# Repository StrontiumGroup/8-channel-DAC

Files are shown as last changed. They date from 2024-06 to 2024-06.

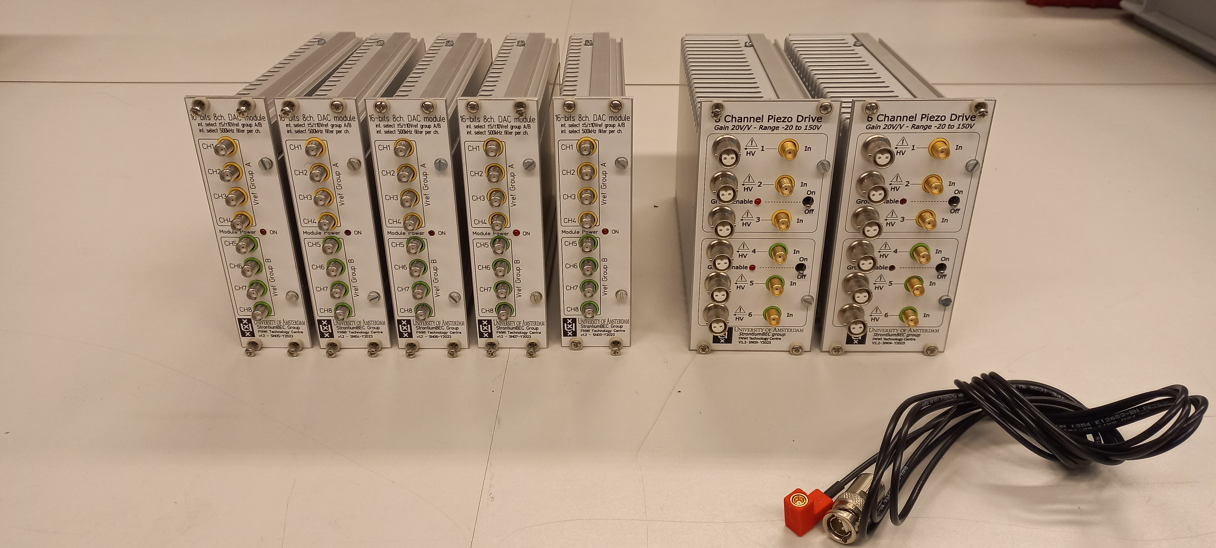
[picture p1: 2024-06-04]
Pictures/SN03-7.jpg

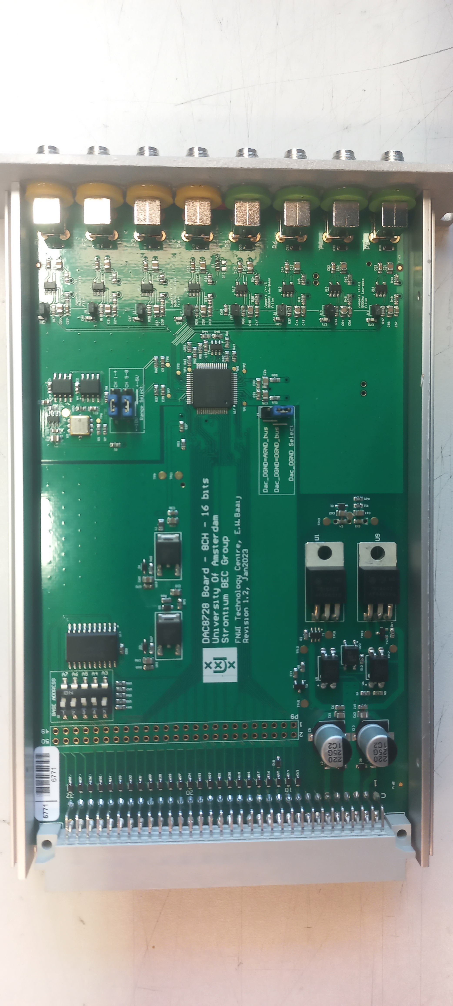
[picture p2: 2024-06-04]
Pictures/SN02/20230306_154427.jpg

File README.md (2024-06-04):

DAC_Module_V12_2
DAC_Module_V12_1
SN03-7 modified
Untitled picture2
![Uploading Untitled picture.png…]()

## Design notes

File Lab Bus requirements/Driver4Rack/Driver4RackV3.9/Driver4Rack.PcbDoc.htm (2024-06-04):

Reporting Options

# File in Previous Format

Date | : | 24/06/2022
Time | : | 11:39:30
Filename | : | U:\iqclock\Electronics\Designs\Driver4Rack\Driver4RackV3.9\Driver4Rack.PcbDoc

Version | Warning
Release 12 | CAUTION - Air Gap Width previously controlled by Clearance rule is now controlled by Polygon Connect Style rule's newly introduced Air Gap Width (set to default value). Suggest reviewing each Polygon Connect Style rule's Air Gap Width attribute for correctness.
Release 13 | CAUTION - Silkscreen Over Component Pads Rules are converted to Silk To Solder Mask Clearance Rules. Suggest examining rule scopes for accuracy.

This file was generated by an earlier version of the software

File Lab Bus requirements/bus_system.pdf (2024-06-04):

A Simple Parallel Bus

Computer Control System
for Atomic Physics Experiments

### Todd P. Meyrath¹ Florian Schreck

Atom Optics Laboratory
Center for Nonlinear Dynamics University of Texas at Austin

c 2004 by the authors
March 6, 2004
revised March 25, 2004

Here we present a simple computer control system concept based on a parallel 16-bit bidirectional data bus, parallel 8-bit address bus, and strobe signal. This represents a particularly simple to understand and flexible system that is suited for a wide range of experimental control. In particular, we use it for cold atom experiments. Nothing here is specific to atom physics, many experimental systems could benefit from such a control system. Although these concepts are well known in the hardware community and everything here represents old technology, much has been unknown to the experimental atom physics community. Our implementation may be considered a brute-force method were most devices used can largely be considered unintegrated whereas they are very flexible and appropriate for use as laboratory electronics. The simplicity of the parallel bus allows easy interfacing with many devices including Digital-to-Analog Converter (DAC), Analog-to-Digital Converter (ADC), Direct Digital Synthesis (DDS), microprocessors, etc. Another important aspect of this method is simplicity of construction in that the hardware is available from many electronics distributors and can be fabricated in a few weeks by undergraduates or graduate students.
Figure 1 gives an overview of the system we are using. This setup involves a National Instruments board, however, see below for other implementation ideas. The elements of Figure 1 are as follows:
- Part A: The National instruments card requires a special cable using a peculiar hardware connector. The order of the signal lines are awkward on this cable. Adapter board A sorts the signals out and distributes them to four 8 bit flat ribbon connectors.
- Part B: Cable B has to be constructed combining those four 8 bit flat ribbon cables in one 25 bit and one 7 bit flat ribbon cable. The bit order of this cable

1Please send comments, questions, corrections, insults to meyrath@physics.utexas.edu

1

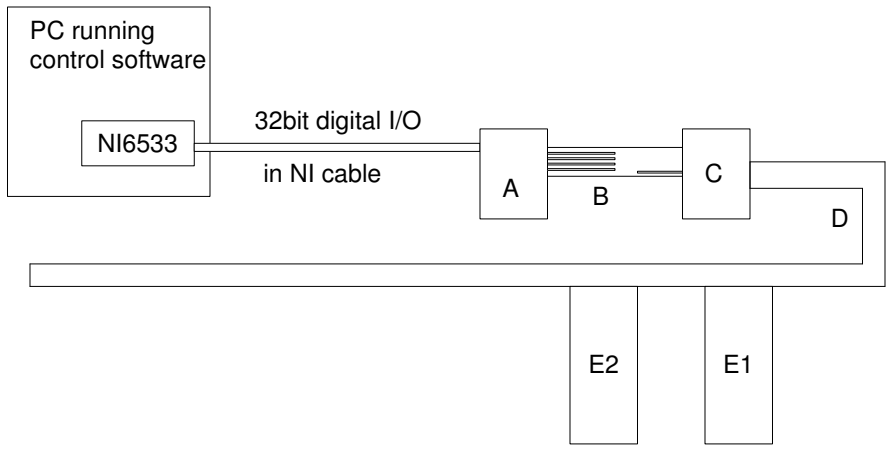
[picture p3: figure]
PC running control software; 32bit digital I/O; in NI cable

A: NI cable to flat ribbon cable converter board

NI = National Instruments

B: 4x 8 bit to
1x25 bit + 1x7 bit
converter flat ribbon cable

C: bus transceivers and
strobe pulse generator board D: 25 bit flat ribbon bus cable

Ex: digital or analog output PCB

Remark: the NI6533 cards and parts A,B can be exchanged eg. with the USB port and a USB to parallel converter

Figure 1: General layout of the control system.

is the obvious one, port A,B,C, and bit 0 of port D go to the 50 pin header (see below) and bits 1 to 7 of port D go to the 7pin header. Signal and ground lines alternate in the flat ribbon cables. The headers must be crimped in the correct orientation on the cable so that bit zero of port A goes to bit 0 of the 25 bit bus and so forth. We used a 50 line flat ribbon cable and an additional 14 line cable next to it.

- Part C is the strobe bit generator and transceiver board. It buffers the NI6533 card signals in addition to producing a time shortened strobe bit signal. The schematic and layout are at the end of this document.
- Part D is the bus system 50 line flat ribbon cable. The pin configuration com-patible with our output devices is given below. It is suggested that an additional buffer board be used if the ribbon cable it to travel a long distance.
- Part E1: 16-bit devices.

Concept: The concept of the system is illustrated in Figure 3. The system consists of a 16-bit data bus, an 8-bit address bus, and a clock. The clock is converted into a strobe signal. The strobe commands the device to update its data, see next

2

section. All 25 bits are sent to all devices but only one accepts the data. Each device has a local 8-bit address which is set on the Printed Circuit Board (PCB) of that device with DIP switches. Only when the input 8-bit address bus matches does the device accept the strobe signal. With this system, one may add up to 2⁸ devices onto the bus, one of which is accessed each clock cycle.
The data bus, in fact, may be bidirectional which allows for input data as well. Our buffer/strobe generator board (see below) includes transceiver buffers which can operate bidirectionally. This requires an additional bit in the bus which talks to this board and chooses the data bus direction. In this case, it is the responsibility of the computer to address the appropriate input device. As of this writing, we have not implemented the use of this input option, but it is in principle a simple addition.

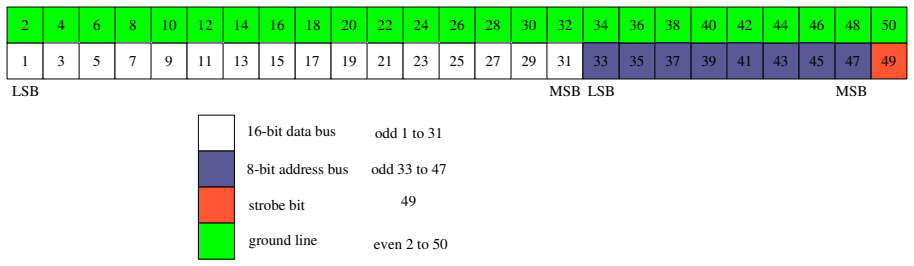
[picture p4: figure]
16-bit data bus; 8-bit address bus; strobe bit; ground line; LSB; MSB; odd 1 to 31; odd 33 to 47; even 2 to 50

Figure 2: Pin configuration for 50-pin connector.

Why a Strobe? The strobe serves two purposes: increase data rate and signal error protection. Firstly, the data loading implementation in a similar system is typically accomplished in three clock cycles: data input, strobe on, strobe off. This can be improved by using a time shortened pulse for the strobe rather than full clock cycles. The strobe pulse occurs in the center of each clock period and has no dependance on clock state, only state change. Our strobe pulses are typically order 100 ns in length in the middle of the order 2 µs (500 kHz clock) clock periods. This concept, along with out circuit implementation schematic is shown in Figure 4. The figure inset shows a pictorial diagram of the strobe timing.
Computer Output: How the computer actually generates the needed bus bits is flexible. The method we currently use involves a N16533 from National Instruments. This device gives an synchronous 32-bit parallel bus and clock signal which we have typically run between 500 kHz and 750 kHz. Such a fancy device is not to-tally needed (we used it because we had it). The computer outputs can be produced synchronously using other methods, a few of which we will suggest here in words. One method that could be used is the computer’s built-in parallel printer port. This port has an 8-bit parallel I/O and various handshaking bits. In this case, the clock would be put external to the computer along with an 8-bit output FIFO, 24 or 32-bits worth of latches (74LS573) and a few logic chips. The basic idea is to put the asyn-chronous computer output of the parallel port into the FIFO which is synchronously triggered by the local clock and multiplexed to 24 or 32 bits and latched. The FIFO is First In First Out and consists of a triggered buffer, there are bunches of single

3

chip FIFOs available. A similar option is to use a USB device such as DLP-USB245M (available from mouser electronics for $25). This device accepts a USB (Universal Serial Bus) connection from the computer and has a built-in synchronous FIFO 8-bit parallel output and would require only a few logic chips and latches to implement. Evidently the manufacturer of this USB-FIFO device provides all the simple codes for programming the device, although we have not used it. The only real disadvantage of these two suggestions to the National Instruments card is the bus speed which may be limited to a few hundred kHz. The two major advantages of these systems are: they are really cheap (order $50) compared to NI cards (order $1500), and secondly, with the printer port or USB port implementation, it is portable to any computer. Another interesting option could be to use a Firewire port and implement it similar to the USB as discussed here if some convenient protocol devices exist. Firewire has the advantage of running at 300Mbps (tak bystro!).
Example Devices: Our goal here is flexible laboratory electronics. A com-mon laboratory implementation uses BNC type outputs which connect devices under computer control to the real-world experimental (analog) devices. Typically, desired computer output comes in the form of lone digital trigger signals and analog signals. We, therefore, have built two device types for this bus system. The first is a simple buffered set of digital outputs. In this case a single ‘16-bit device’ as discussed in Figure 3 consists of 16 latched digital outputs equipped with line drivers. The second device type is analog. In this design, we use some very nice modern 16-bit DAC ICs. Here, a single analog line is a 16-bit device. Our design for this includes 8 analog outputs on a single PCB, each of which has a full -10 to +10 V range and 16 bit accuracy as well as 1/4 A line driving capacity. Schematics, layouts and detailed descriptions for both of these device types are available at the web site: george.ph.utexas.edu/~control
Because of the generality of this system, one could easily make other output devices such as DDS type radio frequency generators, etc. Additionally, as discussed before, ADC’s could be added using the input mode of the data bus.

4

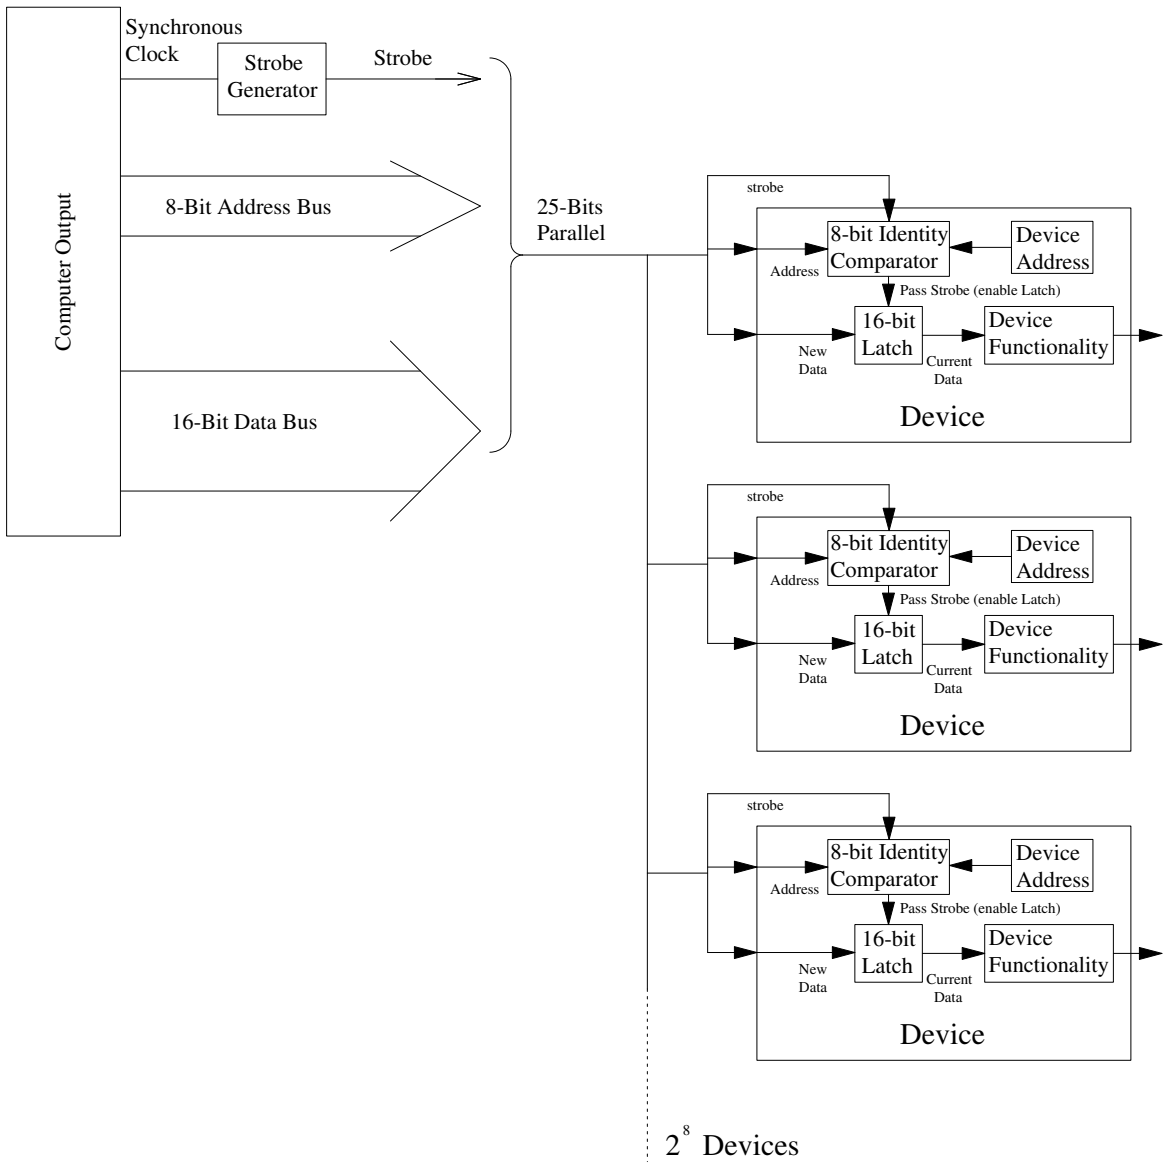
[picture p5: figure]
Synchronous; Clock; Strobe; Generator; 8-Bit Address Bus; 16-Bit Data Bus; Computer Output; 25-Bits Parallel; Device; Device Address; 8-bit Identity Comparator; Device Functionality; Current Data; 16-bit; New; Latch; Data; Address; Pass Strobe (enable Latch); strobe; 2 Devices ⁸

Figure 3: Output Concept. Each 16-bit device has its own 8-bit address which typically may be set locally with DIP switches. All devices receive all 25 bits on each clock cycle, but only the device with matching address accepts the strobe bit which commands it to take the new data.

5

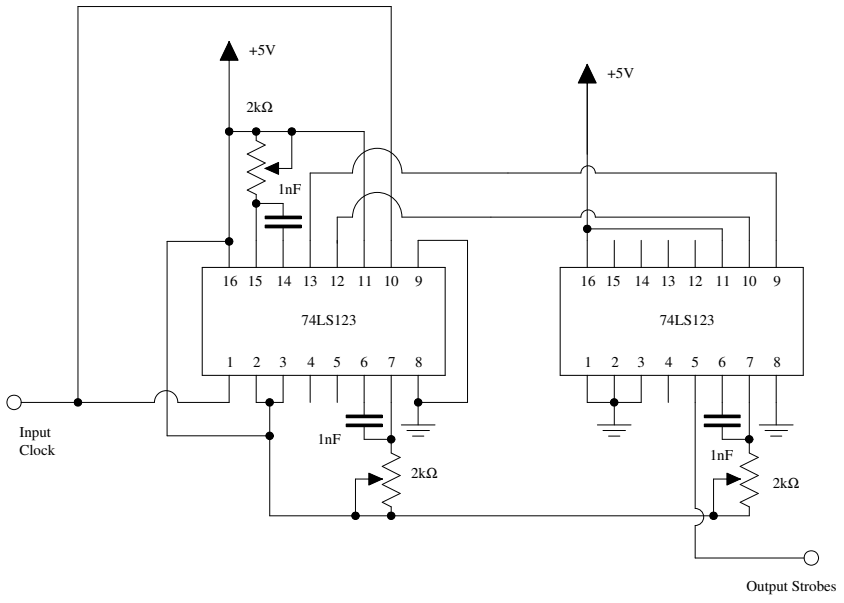
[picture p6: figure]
Input Clock; Output Strobes
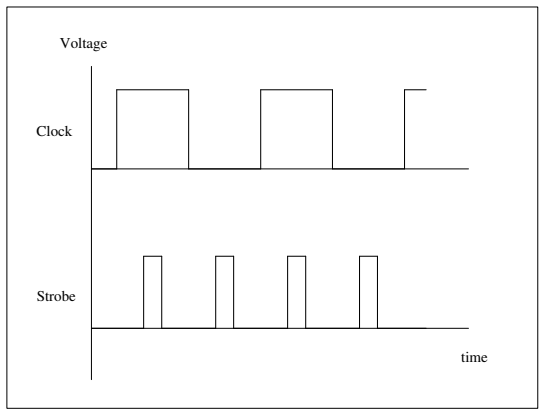
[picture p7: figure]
time; Voltage; Clock; Strobe

Triple Data Rate Strobe

Figure 4: Strobe Generator. Note, that the strobe bit can be high or low active (switching output pins 12 to 5). In this design, we have chosen it to be high because that is the logic used on our digital output board designs. Please note in the case of the analog output board, that the active strobe may be chosen to be high or low. Which is to say, for using this strobe generator design, the analog output boards must always have the DIP switch set to properly accept a high strobe. See documentation on the digital and analog output board designs.

6

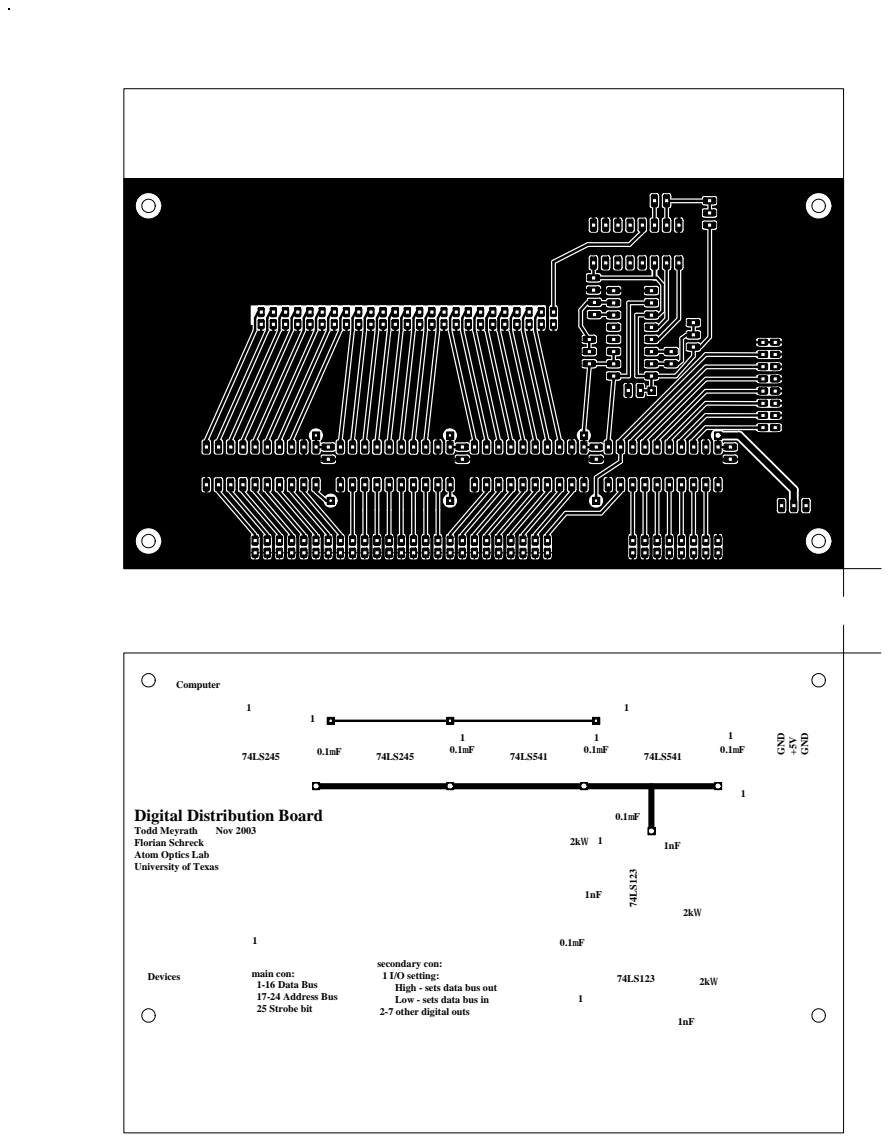
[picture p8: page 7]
Computer; Devices; main con:; 1-16 Data Bus 17-24 Address Bus 25 Strobe bit; GND; Todd Meyrath; Nov 2003

Digital Distribution Board
Florian Schreck
Atom Optics Lab
University of Texas

secondary con:
1 I/O setting:
High - sets data bus out
Low - sets data bus in
2-7 other digital outs

Bus buffer, strobe generator and NI6533 adapter board

Gerhard Hendl, Florian Schreck and Todd Meyrath

This board provides several functions: it is an adapter between the NI6533 cable and the 50 pin header of the bus system, it can generate a strobe signal and it can have input lines for the NI6533 external clock and trigger. It can also be used just as a signal refreshing board within the 50 pin bus cable. It is possible to add zener diodes between the bus signal lines and ground to improve the signal quality. The remaining normally unused 7 bits of the NI6533 are available on a independent connecter. Those bits can for example be used in conjunction with an address decoder chip to put the strobe signal to the bus only if a certain bit pattern appears on these higher seven bits. In that way it is possible to use more than 256 different addresses. Or these bits can be used as additional digital outputs.
This board was designed by Gerhard Hendl of the institute for quantumoptics and quantuminformation of the Austrian academy of sciences at Innsbruck (gerhard.hendl at oeaw.ac.at).

1

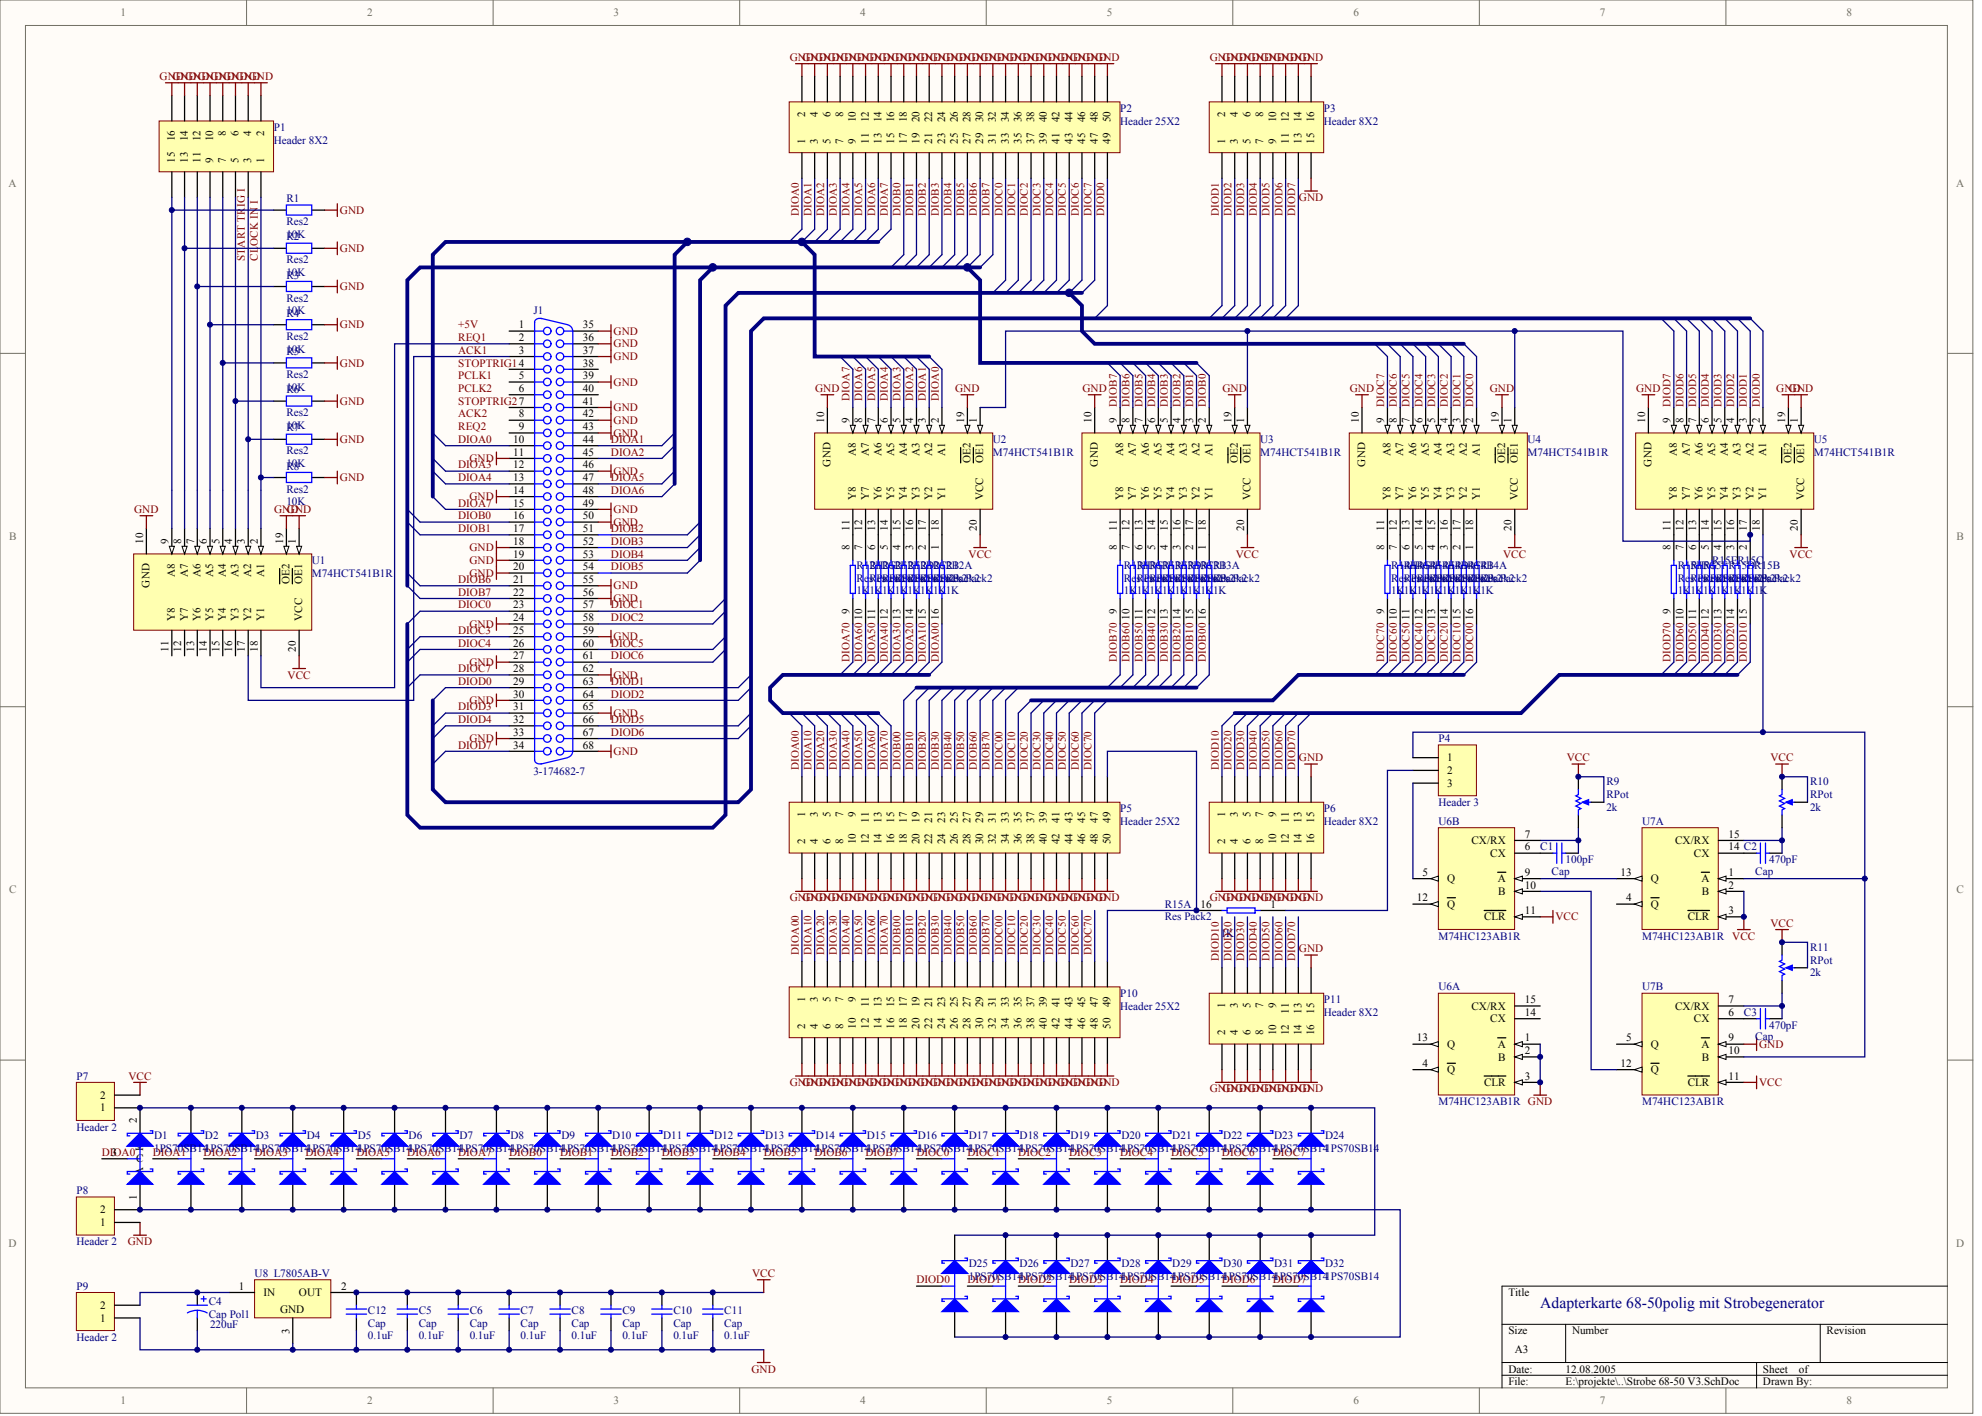
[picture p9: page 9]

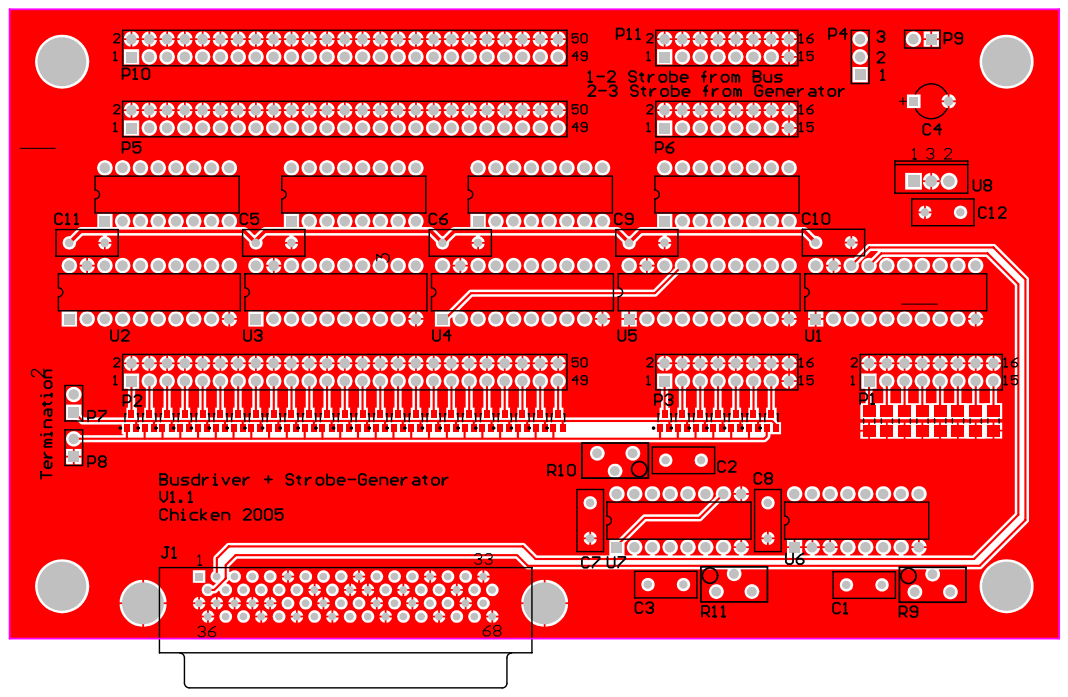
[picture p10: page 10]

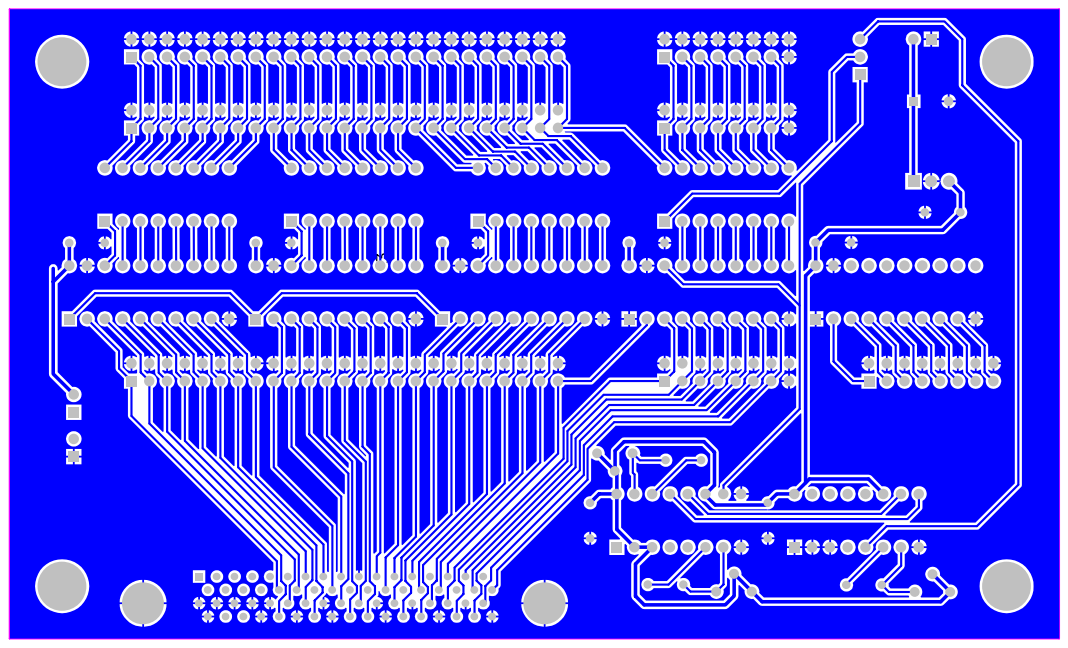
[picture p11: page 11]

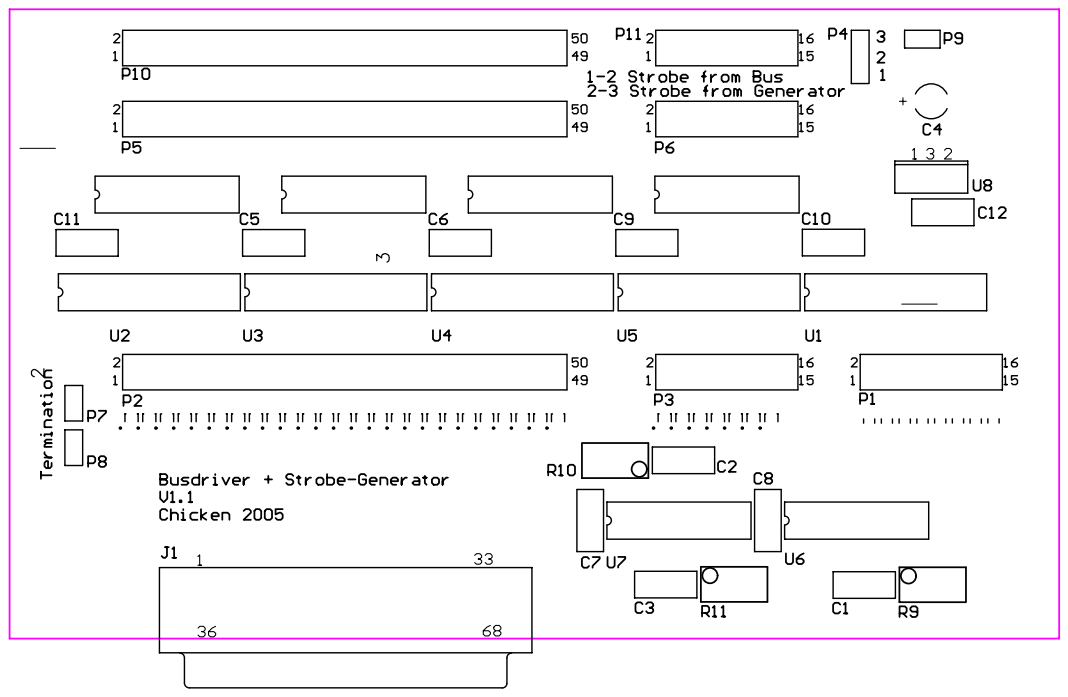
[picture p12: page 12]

Designator Description | Value LibRef | Footprint
C1 | Capacitor | 100pF Cap | RAD-0.2
C2 | Capacitor | 470pF Cap | RAD-0.2
C3 | Capacitor | 470pF Cap | RAD-0.2
C4 | Polarized Capacitor (Radial) | 220uF Cap Pol1 | CAPPR5-5x5
C5 | Capacitor | 0.1uF Cap | RAD-0.2
C6 | Capacitor | 0.1uF Cap | RAD-0.2
C7 | Capacitor | 0.1uF Cap | RAD-0.2
C8 | Capacitor | 0.1uF Cap | RAD-0.2
C9 | Capacitor | 0.1uF Cap | RAD-0.2
C10 | Capacitor | 0.1uF Cap | RAD-0.2
C11 | Capacitor | 0.1uF Cap | RAD-0.2
C12 | Capacitor | 0.1uF Cap | RAD-0.2
D1 | Schottky Barrier Double Diode | 1PS70SB14 | SOT323
D2 | Schottky Barrier Double Diode | 1PS70SB14 | SOT323
D3 | Schottky Barrier Double Diode | 1PS70SB14 | SOT323
D4 | Schottky Barrier Double Diode | 1PS70SB14 | SOT323
D5 | Schottky Barrier Double Diode | 1PS70SB14 | SOT323
D6 | Schottky Barrier Double Diode | 1PS70SB14 | SOT323
D7 | Schottky Barrier Double Diode | 1PS70SB14 | SOT323
D8 | Schottky Barrier Double Diode | 1PS70SB14 | SOT323
D9 | Schottky Barrier Double Diode | 1PS70SB14 | SOT323
D10 | Schottky Barrier Double Diode | 1PS70SB14 | SOT323
D11 | Schottky Barrier Double Diode | 1PS70SB14 | SOT323
D12 | Schottky Barrier Double Diode | 1PS70SB14 | SOT323
D13 | Schottky Barrier Double Diode | 1PS70SB14 | SOT323
D14 | Schottky Barrier Double Diode | 1PS70SB14 | SOT323
D15 | Schottky Barrier Double Diode | 1PS70SB14 | SOT323
D16 | Schottky Barrier Double Diode | 1PS70SB14 | SOT323
D17 | Schottky Barrier Double Diode | 1PS70SB14 | SOT323
D18 | Schottky Barrier Double Diode | 1PS70SB14 | SOT323
D19 | Schottky Barrier Double Diode | 1PS70SB14 | SOT323
D20 | Schottky Barrier Double Diode | 1PS70SB14 | SOT323
D21 | Schottky Barrier Double Diode | 1PS70SB14 | SOT323
D22 | Schottky Barrier Double Diode | 1PS70SB14 | SOT323
D23 | Schottky Barrier Double Diode | 1PS70SB14 | SOT323
D24 | Schottky Barrier Double Diode | 1PS70SB14 | SOT323
D25 | Schottky Barrier Double Diode | 1PS70SB14 | SOT323
D26 | Schottky Barrier Double Diode | 1PS70SB14 | SOT323
D27 | Schottky Barrier Double Diode | 1PS70SB14 | SOT323
D28 | Schottky Barrier Double Diode | 1PS70SB14 | SOT323
D29 | Schottky Barrier Double Diode | 1PS70SB14 | SOT323
D30 | Schottky Barrier Double Diode | 1PS70SB14 | SOT323
D31 | Schottky Barrier Double Diode | 1PS70SB14 | SOT323
D32 | Schottky Barrier Double Diode | 1PS70SB14 | SOT323
J1 | Plug Assembly, Horizontal with Kink | 3-174682-7 | 3-174682-7
P1 | Header, 8-Pin, Dual row | Header 8X2 | HDR2X8
P2 | Header, 25-Pin, Dual row | Header 25X2 | HDR2X25
P3 | Header, 8-Pin, Dual row | Header 8X2 | HDR2X8
P4 | Header, 3-Pin | Header 3 | HDR1X3
P5 | Header, 25-Pin, Dual row | Header 25X2 | HDR2X25
P6 | Header, 8-Pin, Dual row | Header 8X2 | HDR2X8
P7 | Header, 2-Pin | Header 2 | HDR1X2
P8 | Header, 2-Pin | Header 2 | HDR1X2
P9 | Header, 2-Pin | Header 2 | HDR1X2

P10 | Header, 25-Pin, Dual row | | Header 25X2 | HDR2X25
P11 | Header, 8-Pin, Dual row | | Header 8X2 | HDR2X8
R1 | Resistor | 10K | Res2 | cr3216-1206
R2 | Resistor | 10K | Res2 | cr3216-1206
R3 | Resistor | 10K | Res2 | cr3216-1206
R4 | Resistor | 10K | Res2 | cr3216-1206
R5 | Resistor | 10K | Res2 | cr3216-1206
R6 | Resistor | 10K | Res2 | cr3216-1206
R7 | Resistor | 10K | Res2 | cr3216-1206
R8 | Resistor | 10K | Res2 | cr3216-1206
R9 | Potentiometer | 2k | RPot | rpot3
R10 | Potentiometer | 2k | RPot | rpot3
R11 | Potentiometer | 2k | RPot | rpot3
R12 | Isolated Resistor Network - Parts | 1K | Res Pack2 | DIP-16
R13 | Isolated Resistor Network - Parts | 1K | Res Pack2 | DIP-16
R14 | Isolated Resistor Network - Parts | 1K | Res Pack2 | DIP-16
R15 | Isolated Resistor Network - Parts | 1K | Res Pack2 | DIP-16
U1 | Octal Bus Buffer with 3 State Outputs | M74HCT541B1R DIP20
U2 | Octal Bus Buffer with 3 State Outputs | M74HCT541B1R DIP20
U3 | Octal Bus Buffer with 3 State Outputs | M74HCT541B1R DIP20
U4 | Octal Bus Buffer with 3 State Outputs | M74HCT541B1R DIP20
U5 | Octal Bus Buffer with 3 State Outputs | M74HCT541B1R DIP20
U6 | Dual Retriggerable Monostable Multivibrator | M74HC123AB1R DIP16
U7 | Dual Retriggerable Monostable Multivibrator | M74HC123AB1R DIP16
U8 | Precision 1A Regulator | | L7805AB-V | TO220ABN

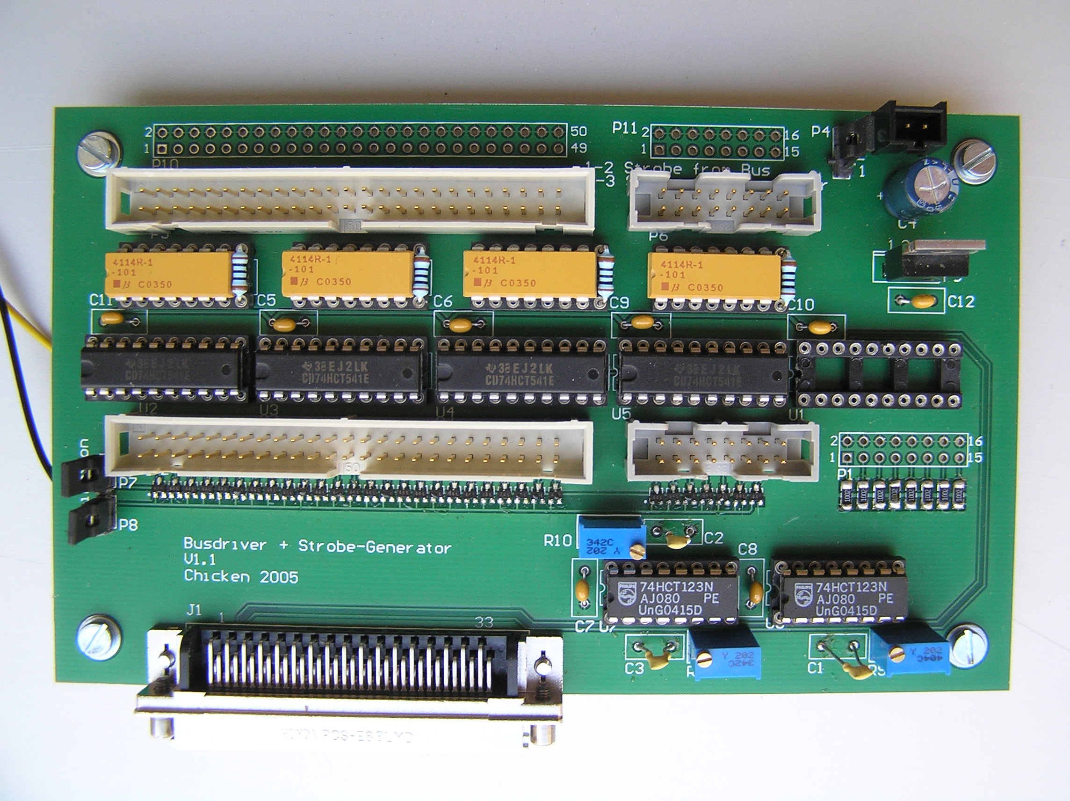
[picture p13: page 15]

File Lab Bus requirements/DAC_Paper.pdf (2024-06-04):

Octal 16-Bit DAC

### Todd P. Meyrath¹ Florian Schreck

Atom Optics Laboratory
Center for Nonlinear Dynamics University of Texas at Austin

c 2004 by the authors
December 14, 2003
revised March 24, 2005

See disclaimer²

Here, we present the design of an octal 16-bit DAC based on the DAC7744 from Texas Instruments. The device here is general purpose and may be easily controlled by a variety of systems involving a simple parallel bus. The basic features are as follows:

Eight channels per board:

- 8-Bit parallel input address bus (plus one strobe bit, 9 total)
- 3 lowest bits select DAC on board (see output table below), the other 5 bits are board select with local address set by DIP switches. The strobe bit also has a DIP switch so it may be set as a high or a low strobe as desired.
- typical digital clock frequency may be 100 kHz to 1 MHz (we use 500 kHz) for 24 input bits (plus one time narrowed strobe bit), 12 to 24 Mbps.

Each Channel:

- 16-Bit accuracy
- ±10V scale, reference drift 3ppm/C, easy to change to ±5V by using different values of the LT1019 reference series.
- Buffered BNC outputs for 50 Ω loads, 250 mA max per channel

Advantages and Disadvantages:
The circuit is relatively simple to understand from the schematic and is competi-tive with professional output boards such as those produced by National Instruments.

1Please send comments, questions, corrections, insults to meyrath@physics.utexas.edu 2Disclaimer: The author provides this and other designs on the web as a courtesy. There is no guarantee on this or any other designs presented, use at your own risk. The author also comments that the suggested parts used are not an endorsement of any manufacturer or distributer.

1

A principle disadvantage of this design is cross talk. As opposed to a design with

### 8 totally independent DACs and voltage references, this design uses the DAC7744

quad DAC sharing voltage references among the four outputs. This may produce cross talk of order the least significant bit between the four channels when sweep-ing. The circuit has several advantages: firstly, it is inexpensive in comparison to National Instruments boards (order $1500). This circuit costs about $200 ($50 per PCB when buying 10, $45 per DAC IC (2), plus output buffers, opamps, capacitors, logic circuits) and the fun of building it yourself! A second advantage is the control bus, this setup allows one to set up a data and address bus system however one wants (digital output board, parallel port, USB to parallel, etc). The addressing and data writing is very simple with a 16-bit parallel data bus and an 8-bit parallel address bus. This means that the computer may control many such boards or other types using a similar bus setup. The digital lines may also extend far from the computer along a single 50 conductor ribbon cable. This may allow one to keep the precision analog outputs short. Our system using 8 address bits may have as many as 256 16-bit analog outputs (unless addresses are used for other devices as well). Naturally only one 16-bit output may be addressed on a single digital cycle, however, for the cold atom experiments that we run this is hardly a limitation. We run our digital bus at 500 kHz. The circuit is in convenient form for laboratory electronics with BNC outputs which are buffered to drive the common 50 Ω loads. The board may be easily panel mounted in an enclosure using the BNC receptacles. Such output stages are not available straight from the various (National Instruments) PCI boards and therefore must be externally added (at great expense) – which requires a similar amount of labor to construct as these designs. The generality of the bus system to run these boards is a major advantage in terms of extendibility. Where as, PCI (or PXI) type analog boards have the major constraint of limited PCI slots.
One can also consider this design in comparison to the old-fashioned method of saving money – using potentiometers. Here, we have about $25 for a fully flexible stable analog output. Most potentiometers cost from $10 to $15 and a precision locking knob can cost a similar amount, plus the minor expenses of voltage references, potentiometer designs are not much cheaper, if at all.
The limit on the speed here is the settling time of the DAC which is specified to be 0.003% in 10 µs Giving a not-as-settled output for our clock rate. In principle, if this is tolerable, the update time can be sub-µs. There is also a limitation introduced by the lack of impedance matching on the board’s digital inputs, however this should not be a problem until far beyond reasonable update times for these DACs. Should the bus system be run at a much higher frequency in any case, an impedance matched buffer board may become necessary near the digital inputs to the DAC board.

Outputs:
Output BNCs are labeled J1 to J8 left to right on the front panel. Their addresses are given in the following table, where X’s are setable for board select. Address bits are referred to as bits 0 to 7 and bit 8 is strobe.

2

Board Version 2
Address | Output Conn. | Label
XXXXX 111 | J1 | Out 7
XXXXX 110 | J2 | Out 6
XXXXX 101 | J3 | Out 5
XXXXX 100 | J4 | Out 4
XXXXX 011 | J5 | Out 3
XXXXX 010 | J6 | Out 2
XXXXX 001 | J7 | Out 1
XXXXX 000 | J8 | Out 0
The value of the label is the amount to add to the base address XXXXX000.

Comments on Construction:
Surface soldering is not as hard as it looks! We give two methods here, the first is what we used first which is to solder pins one-by-one. The second is using solder paste, see below under the ‘easier soldering method’. Soldering items to the surface is easy with a standard iron with a small tip (we used a 0.01” tip). The trick is removing them if necessary – you have to obtain special tips or simply cut them away, i.e. with a high speed rotary tool. A few tips for soldering:
- The pads already have a solder mask. Put liquid solder flux on the pads before soldering.
- Use a small set of tweezers and dental tools to position the items. A thin piece of tape may be useful for holding the ICs down for the initial solder connections.
- For SOICs and 1206 chips (resistors and capacitors) it is easy to simply solder one pin while gently pressing the item downwards to keep it from moving. Once one half of the 1206 or a few pins of the SOIC are attached, it is easy to solder the others. The trick is holding the item steady while attaching it in the first place, but this may be done with tape.
- Very small pins, such as the SSOP package (the DAC), require special attention. A procedure for soldering the DAC is shown in Figure 1 and is as follows: (a) A clean new board has a solder mask, the solder mask does not have enough solder to attach the pins reliably to the board. (b) Apply liquid solder flux to the pins. (c) Add solder to each pin, this can be done by smearing solder from the iron across the pins and then striking them with the iron tip in the long direction. It should leave a semi-sausage on each pin. This additional solder is critical to making a reliable contact. (d) Apply more solder flux. (e) Place the chip on the pad and attach with masking tape. The IC will not lay perfectly flat, but close if the additional solder is sufficiently uniform, it is not totally important. (f) Heat pins in sets with a clean iron. This causes the solder to flow and stick to the pins. It may be useful to press the IC with a finger as well.
(g) Remove tape, the IC is now attached to the board. (h) Apply more solder
| 3

flux. (i) Heat pairs of pins and pads adding a small amount of solder each time. Keep the iron hot so that a small amount of solder will go to the iron tip. Be sure to hold long enough to allow the solder to reflow at the pin. Do not add too much solder at risk of attaching neighboring pins together. (j) Finished soldering, each pin should have a shiny solder bead. (k) Clean off solder flux with isopropanol or flux remover. For this procedure, we used a 0.01” soldering iron tip. The addition of the solder to the pad is very important, without it, there is little attachment of the bottom of the pads and it is also difficult for solder to flow onto the connection.

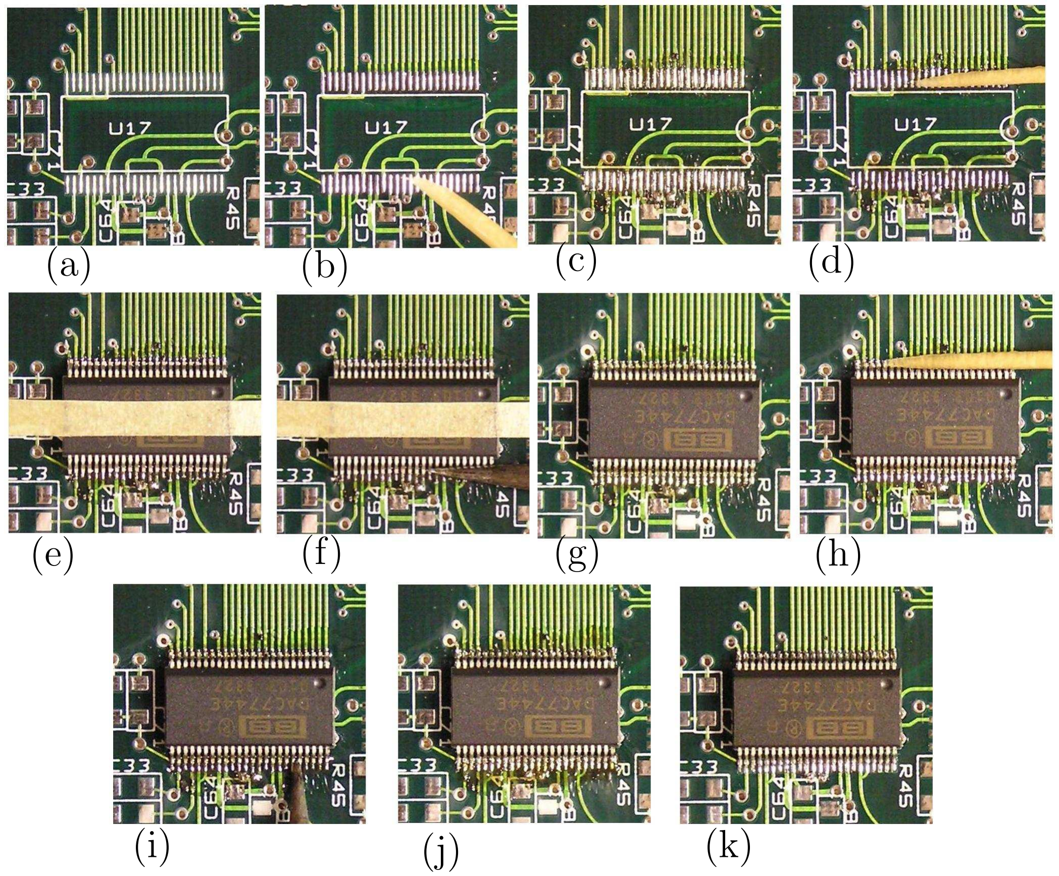
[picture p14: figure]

Figure 1: Soldering the DAC, see text for explaination.

It is suggested to solder items on in the following order:

- The DAC chips: these are the hardest and may require soldering iron acrobat-ics that would be hindered by large components (connectors, capacitors, etc). After the soldering of these ICs, each pin connection should be checked and it should also be verified that there are no solder bridges between pins. It is very important that these connections are all solid, to test this, one may give the board a small amount of torsion while it still has only the 2 DAC ICs. Any bad connections should reveal themselves at this point.
- The SOIC ICs: these are not very difficult, but it is also convenient to not have obstacles.

4

- The passives: the 1206 components are easy. This completes the surface mount devices.
- The through-hole devices: the connectors, large capacitors, DIP switches, BUF634 ICs. Every kindergartner knows how to solder these.

Easier Soldering Method: We used solder paste (Kester water based solder paste, KE1512-ND from Digikey electronics). The solder paste is applied to the pins. For the solder reflow, we used a standard toaster oven and brought the temperature to about 220oC. Note: the DAC is a moisture sensitive device, so we first baked it out at about 120oC for several hours. See the website: http://www.seattlerobotics.org/encoder/200006/oven art.htm
for amateur solder paste ideas.

Comments on buffer heat sinking:
It is absolutely necessary that the BUF ICs each have a small heat sink attached to them, even if you expect that it will drive very little current. Un-sinked buffers will over heat in time. These buffers have an internal thermal shut off which means that they will not burn up all by themselves. However, the thermal shut off can cause major errors in output signals. The errors will not manifest themselves as a zero output single but rather large signal spikes and dips as the buffer turns itself off when it gets too hot and then back on again periodically which may typically be on the ms timescale. The simple moral to the story: heat sink the buffers, and use a small fan.

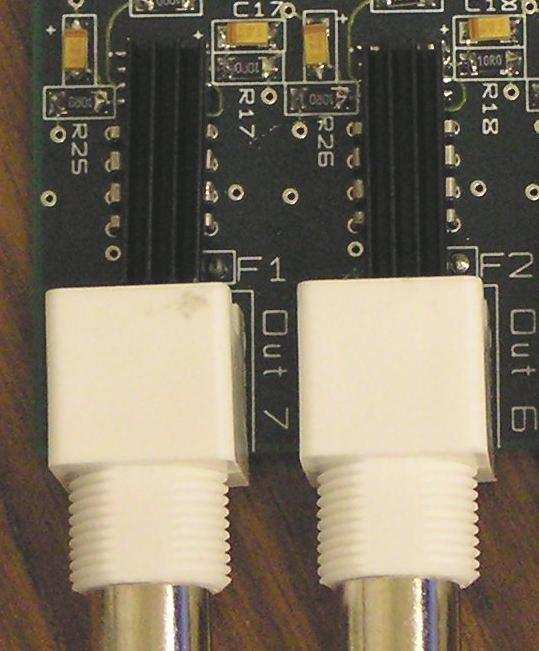
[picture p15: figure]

Figure 2: Heat Sinks. These small heat sinks were simply attached to the top of the BUF ICs with 5 minute epoxy.

The Printed Circuit Board:
The PCB is a four layer board with signal lines on the top and the bottom. The second to the top layer is the location of the two ground planes (one analog and one digital) and the third from the top is the three power planes (+5 V and ±15 V). All ICs are located on the top as well as most passives. There are also various small items on the bottom. The PCB was designed using the free software from PCB123, this company produced our circuit boards. For the design presented here, the PCB cost was $512 for 10 boards including silk layer charges. The software and information is

5

available at the web site www.pcb123.com. The design of the board is shown in the printout pages near the end of this document and the design file is available at the web site
george.ph.utexas.edu/~control

Circuit Theory:
The DAC concept is explained on the DAC7744 data sheet available from Texas Instruments and there is no need to discuss it here. Here we discuss the basic idea of the digital and analog circuits on the board.

Digital Circuit:
The input to the digital side consists of a 50 pin input header for a 50 conductor ribbon cable. The signals are spaced with ground lines between them giving 25 digital signals. The first 16 are the data bit lines, the next 8 are the address bus lines (as discussed above), and the final line is the strobe bit. The logic circuit works as follows. The strobe signal enters the comparator and is sent out if the local address matches. The logic gates after the comparator insure that only one of the DACs receives the chip select (CS) signal to load the new data bits into its memory latch. Address bit

### 2 chooses the DAC IC and bits 0 and 1 choose the channel on that DAC. After the

new data is loaded, the “load DAC” signal moves the data from memory onto the analog output and holds. The load DAC signal is also the strobe bit signal but with a delay line. Note that, for the DIP switches, the ON position indicates a LOW and the OFF position indicates a HIGH as far as the board address is concerned.

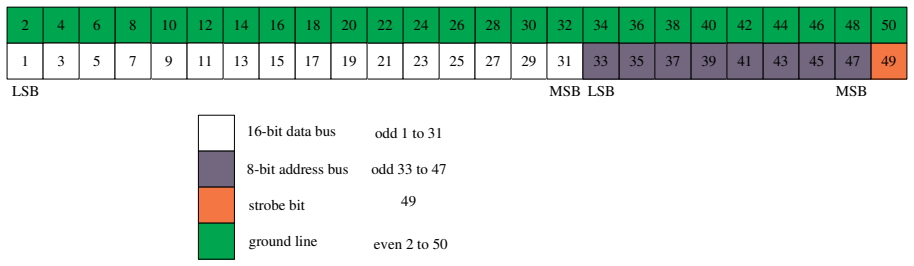
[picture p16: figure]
16-bit data bus; 8-bit address bus; strobe bit; ground line; LSB; MSB; odd 1 to 31; odd 33 to 47; even 2 to 50

Figure 3: Pin configuration for 50-pin connector.

Analog Circuit:
The analog circuit consists of the voltage references and the output buffers. The voltage reference used is the LT1019 from Linear Tech. in the SOIC pkg. We used the 10 V version but it also comes in a 5 V version which may be used with no circuit modification. The other (2.5 V and 4.5 V) may not be used in this circuit without board modification because the DAC requires ±15 V and these lower voltage references can not operate with such supplies. The negative reference is produced with the INA105 in unity inverting mode and has similar stability as the reference itself. The reference inputs use the options given in the DAC7744 data sheet for buffered reference inputs involving the opamp and filter circuit.

6

The output buffers consist of a precision opamp OPA227 and a buffer line driver BUF634. The buffer boosts the current output of the opamp. The output buffer is able to drive an much as 1/4 Amp, such as required if a 50 Ω load is used. In practice, since this device is precision and not high frequency, it is not required to terminate the lines with 50 Ω as it would for high frequency digital lines or RF type sources. However, generally some input load is preferred (i.e. not infinite impedance). A useful receiver circuit appropriate for signals of the sort that this device delivers is given below.
The input filter involving a 10 Ω resistor and 10 µF capacitor on most of the analog ICs is to provide power supply isolation for each chip. This is especially important due to the high current nature of the buffer ICs running on the same power supply.

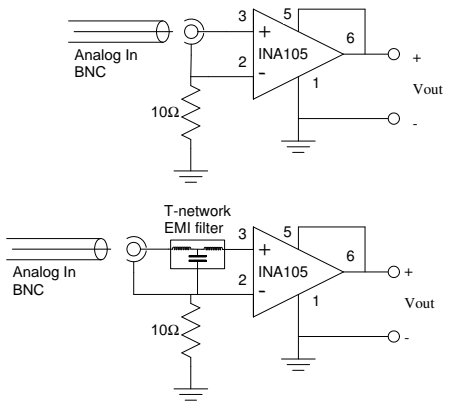
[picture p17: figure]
INA105; T-network; EMI filter; Vout; Analog In BNC

Figure 4: Receiver circuit. These circuits do not appear on the boards described here, but are rather a suggestion for an analog receiver stage of any circuit that the DAC board sources. They use a small resistor 10 Ω to provide voltage separation between the reference ground of the signal source and that of the receiving device. The INA105 unity gain differential amplifier is a precision device with an input resistance of 50 kΩ. This provides a load seen by the source and the differential amplifier should reject common mode noise on the signal line. It should also attenuate high frequency (> 1 MHz) noise on the line, but that can also be improved by adding a T-type EMI filter before the amplifier.

Ground plane comments:
The ground planes (analog and digital) are entirely separate. The power supply grounds do need to be connected at some location however — but not at two. There is a location for an optional ground plane connection on the back of the board. We connected the power supply grounds near the power supplies and operate them for

7

multiple boards. One should be careful in not forming ground loops. If it is decided to connect the ground planes, one should use a ferrite bead rather than a short. If the power supplies share a ground far from the board – if not this forms a ground loop antenna for RF, but the ferrite has an impedance for such frequencies and should prevent this. We used a ferrite similar to that of the digital IC power supply bypass to connect the planes.

8

Modifications for version 2.2: For some loads, the output buffers have high frequency (several MHz) oscillations, here we add an integration on the output opamp: R58 to R65 100 Ω and C76 to C83 10 nF which gives a frequency of 1/2πRC = 160 kHz. At the moment, we have not tested this — in any case, this can be consid-ered an option, if not used replace R58 to R65 with 0 Ω resistors. Also added 100 nF capacitors on BUF supplies C84 to C99.
Modifications for version 2.1: The EMI filter (F1 to F8) and protection diode (D1 to D8) were removed from this version. They caused unexpected problems with different values from the original. It is recommended to do any filtering at the receiver device.
Modifications for version 2.0: Fix problems on version 1.0.
Corrections on version 1.0:
Our first version had the following errors and corrections. These are all fixed on the version given in this paper, these comments are for internal reference.
- Need to invert logic to “Load DAC” pin by adding another inverting gate. Board Correction: On U26, bend pins 2 and 5 up before soldering the chip to the board and then attach them together with a small wire. Use another wire to attach pin 6 to the pad where pin 2 should have gone.
- Need to ground pin 1 of U27 to use the 688 chip. Board correction: connect pin 1 to pin 10.
- Reset DAC pin (pin 17 on U17 and U18) should be connected to +5V not GND for the initial value to be 0V rather than -10V. We did not bother to correct this error on the version 1.0 boards but is fixed for version 2.0.
- Filter capacitors labeled C64 and C65 need to be connected between VrefH and GND and C66 and C67 between VrefL and GND not to the Vref Sense pins. Board corrections: Solder the capacitor to one pad on board and use a small wire to connect to the GND via nearby.
- CS signals go to the reversed DAC, this gives the address table here

Board Version 1.0
Address | Output Conn.
XXXXX 011 | J1
XXXXX 010 | J2
XXXXX 001 | J3
XXXXX 000 | J4
XXXXX 111 | J5
XXXXX 110 | J6
XXXXX 101 | J7
XXXXX 100 | J8

9

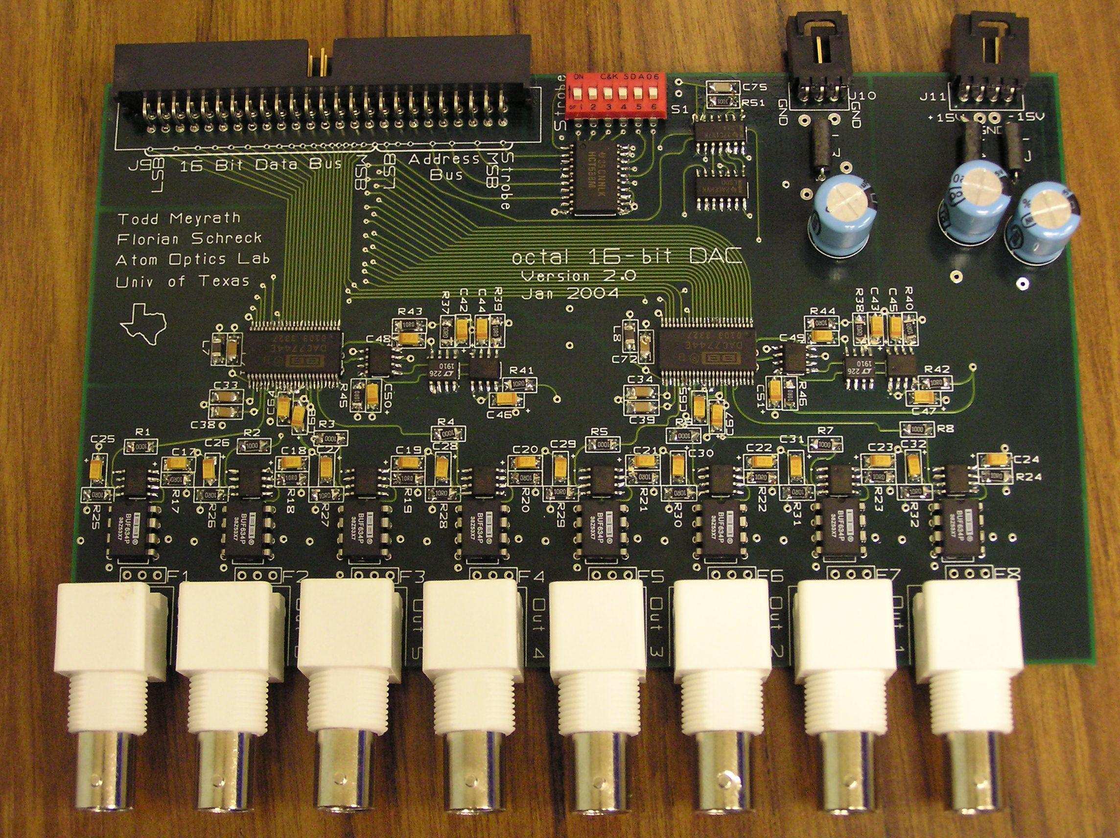
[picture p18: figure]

Figure 5: A completed board, lacking only heat sinks glued onto the BUF chips (this is necessary, see above). Note the DIP switches, as shown here, switch 1 is the strobe,

### 2 is the MSB of the address bus, etc., ON position indicates LOW and OFF position

indicated HIGH as far as the local address goes.

10

Parts
Qu. Label | Part # | Manufacturer/Description
1 | SMBJ5.0A | Vishay Semiconductor / 5 V unidirectional zener †
2 | SMBJ15A | Vishay Semiconductor / 15 V unidirectional zener †
30 | R17-R46 | CRCW120610R0FKTA Vishay/Dale / 10 Ω 1260 pkg resistor.

### 12 R1-R8, R47-

R50

CRCW1206100RFKTB Vishay/Dale / 100 Ω 1260 pkg resistor.

9 | R9-R16, R51 | CRCW12061K00FKTA Vishay/Dale / 1.0 kΩ 1260 pkg resistor.
6 | R52-R57 | CRCW120610K0FKTA Vishay/Dale / 10 kΩ 1260 pkg resistor.
8 | R58-R65 | 100 Ω 1260 pkg resistor.
52 C1-C32,
C36-C37,
C40-C51,
C64-C67,
C73-C74
T491A106M016AS | Kermet / 10 µF solid tantalum surface mnt.

25 C33-C34,
C38-C39,
C71-C73,
C78-C79,
C84-C99
140-CC502B104K | Xicon / 100 nF cap, 1206 chip pkg.
4 | C60-C63 | 12062R222K9B20D | Yageo / 2.2 nF cap, 1206 chip pkg.
3 | C74, C76-C77 | | 470 µF electrolytic capacitor 25 V
1 | C75 | | 120 pF cap 1260 pkg.
8 | C76-C83 | | 10 nF cap 1260 pkg.
3 | L1-L3 | EXC-ELSA35 | Panasonic / radial ferrite beads
5 | L4-L8 | BLM31AF700SN1L | Murata / Surface mount ferrite beads
8 | U1-U8 | BUF634P | Texas Inst. / 1/4 Amp high speed buffer, 8-DIP pkg.
8 | U9-U16 | OPA227UA | Texas Inst. / precision opamp, 8-SOIC pkg.
2 | U17-U18 | DAC7744EB | Texas Inst. / Quad 16-bit DAC, 48-SSOP pkg.
2 | U19-U20 | LT1019CS8-10 | Linear Tech. / 10 V band gap voltage ref, 8-SOIC pkg.
2 | U21-U22 | INA105KU | Texas Inst. / Unity gain prec. diff. amp., 8-SOIC pkg.
2 | U23-U24 | OPA2234U | Texas Inst. / Dual precision opamp, 8-SOIC pkg.
1 | U25 | SN74LS00D | Texas Inst. / Quad 2-input NAND gate, 14-SOIC pkg.
1 | U26 | SN74LS14D | Texas Inst. / Hex schmitt-trigger inverters, 14-SOIC pkg.
1 | U27 | CD74HCT688M | Texas Inst. / 8-Bit Mag. Comp., 20-SOIC wide pkg.
1 | S1 | SDA06H1KD | ITT Ind. 6 pos top slide DIP switch, 12-DIP pkg.
8 | J1-J8 | 31-5431-10RFX | Amphenol / BNC right angle receptacle PCB mnt.
1 | J9 | 1-103310-0 | AMP, Tyco Elect. / 50 pos. right angle conn. header.
1 | J10 | 70553-0002 | Molex / 3 pin right angle header power conn.
1 | J11 | 70553-0003 | Molex / 4 pin right angle header power conn.
1 | | 50-57-9403 | Molex / 3 pin mate housing.
1 | | 50-57-9404 | Molex / 4 pin mate housing.
| | 16-02-0102 | Molex / female crimp pins.
8 | | 501100B00000 | AAvid / Heat sinks
Quantity is per board, label is on the PCB, part # is manufacturer number. Most parts obtained from www.mouser.com, www.digikey.com, or www.alliedelec.com.
†One may consider using these as protection diodes in place of 11 | capacitors C73, C78, C79.

Acknowledgements: The author would like to thank his co-workers on the Raizen Lab’s rubidium BEC experiment: Florian Schreck, Jay Hanssen, and Chih-sung Chuu, and of course Prof. Mark Raizen. Florian’s experience and suggestions were invaluable on this project. We also appreciate the suggestions and corrections offered by Hrishikesh Kelkar and Kevin Henderson.

12

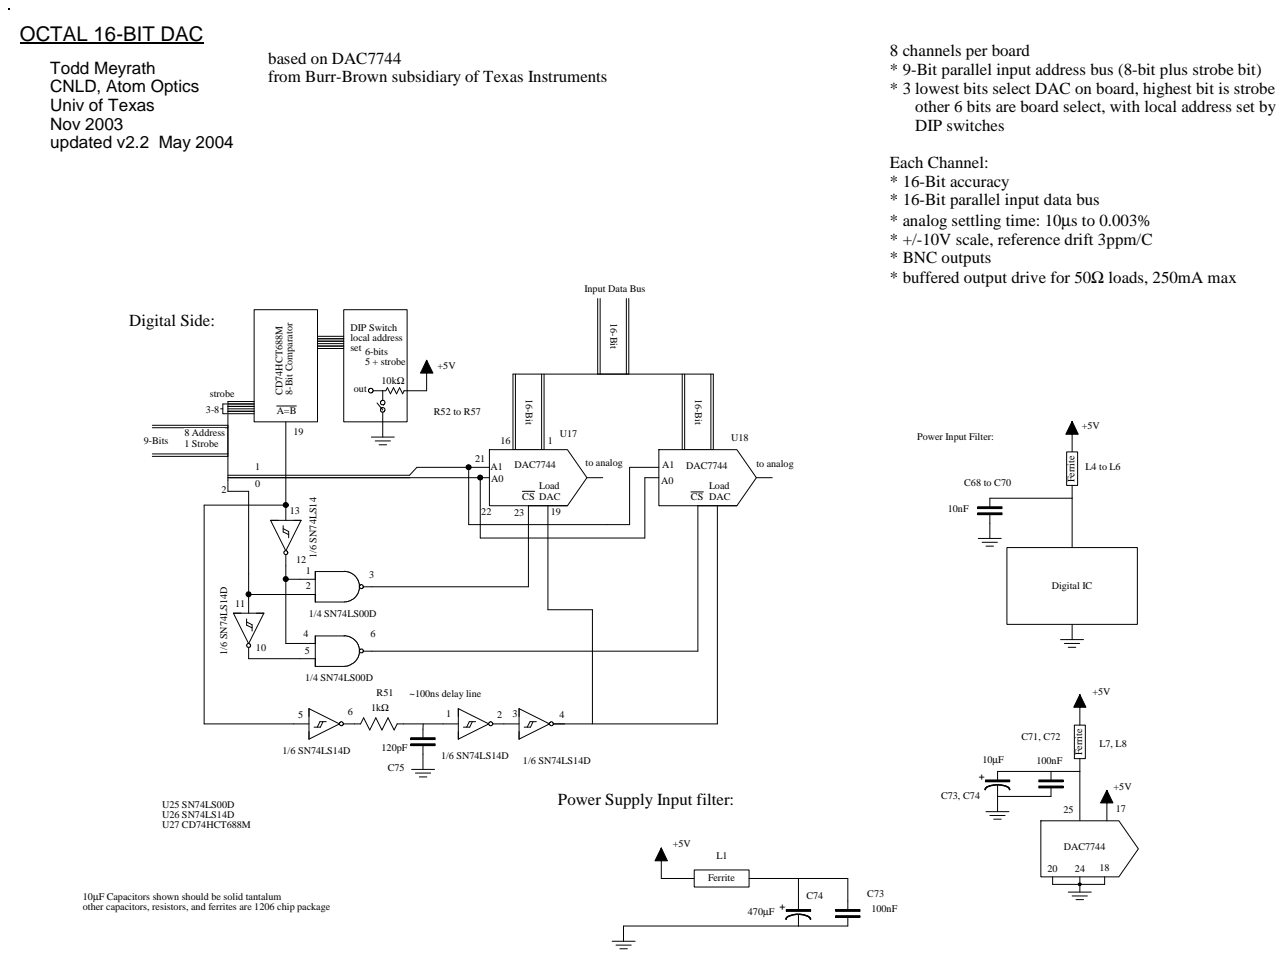
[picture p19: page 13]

based on DAC7744
from Burr-Brown subsidiary of Texas Instruments

8 channels per board
* 9-Bit parallel input address bus (8-bit plus strobe bit)
* 3 lowest bits select DAC on board, highest bit is strobe
other 6 bits are board select, with local address set by
DIP switches

Each Channel:
* 16-Bit accuracy
* 16-Bit parallel input data bus
* analog settling time: 10μs to 0.003%
* +/-10V scale, reference drift 3ppm/C
* BNC outputs
* buffered output drive for 50Ω loads, 250mA max

C73, C74 Power Supply Input filter:

10μF Capacitors shown should be solid tantalum
other capacitors, resistors, and ferrites are 1206 chip package

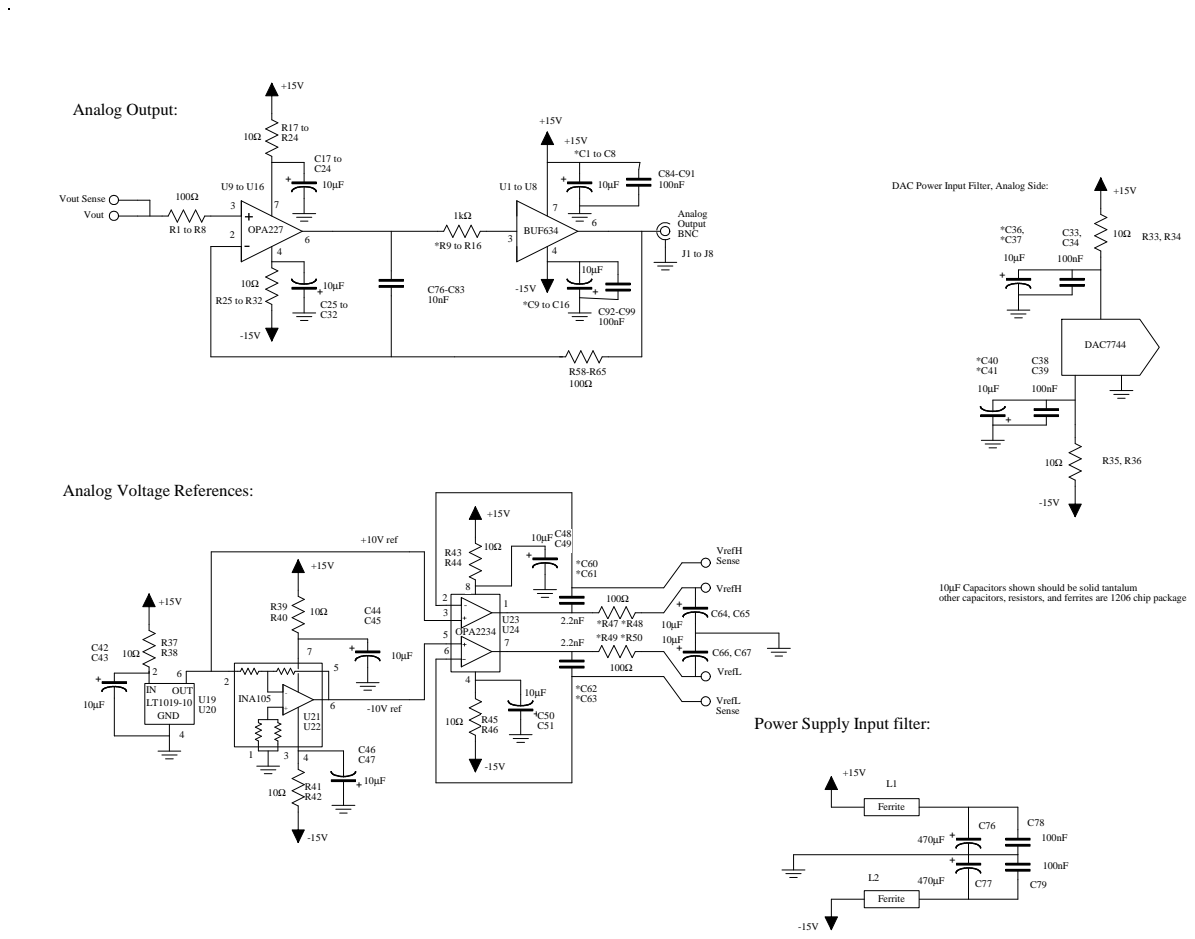
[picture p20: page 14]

DAC Power Input Filter, Analog Side:

10μF Capacitors shown should be solid tantalum
other capacitors, resistors, and ferrites are 1206 chip package

VrefL
Sense
Power Supply Input filter:

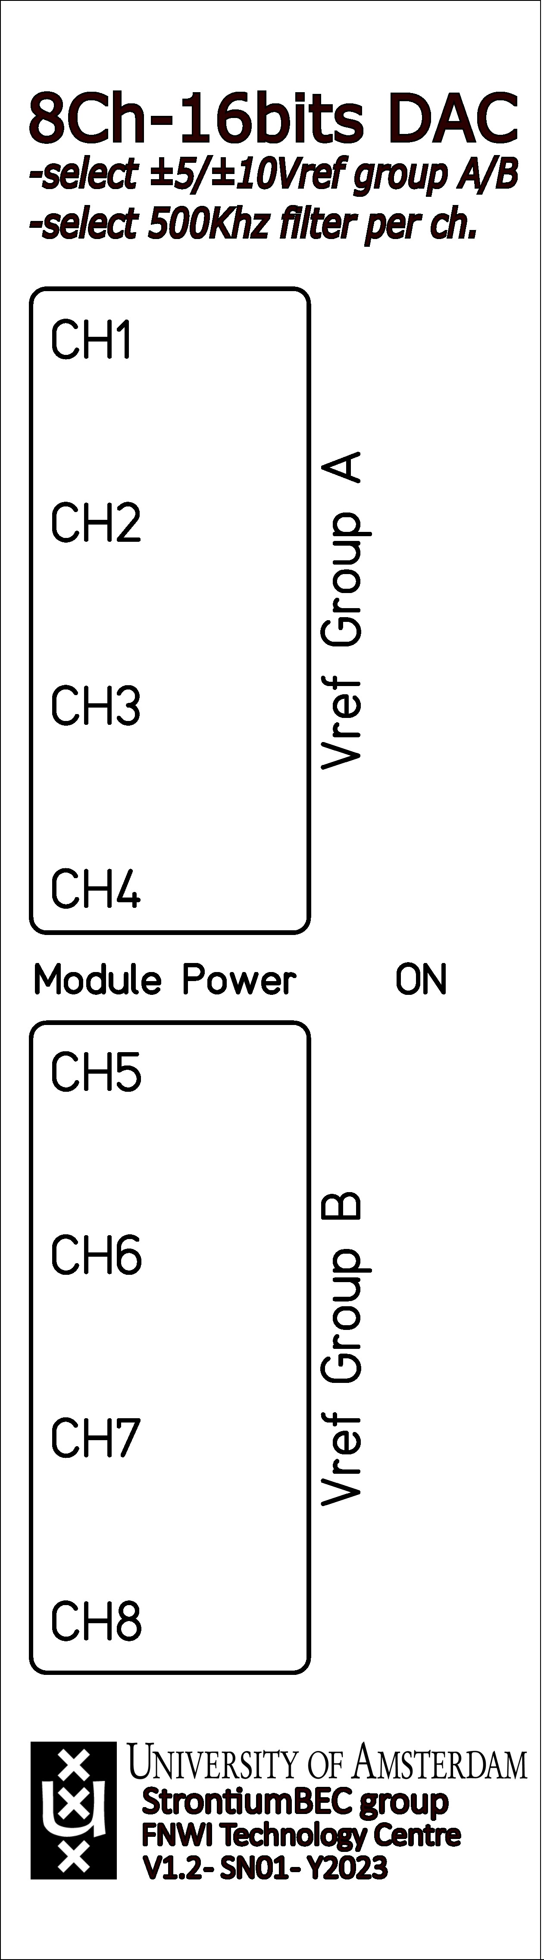
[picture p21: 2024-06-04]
3D CAD/FrontPanelDesigner/FPD Frontplate DAC8728_Board_decal.jpg

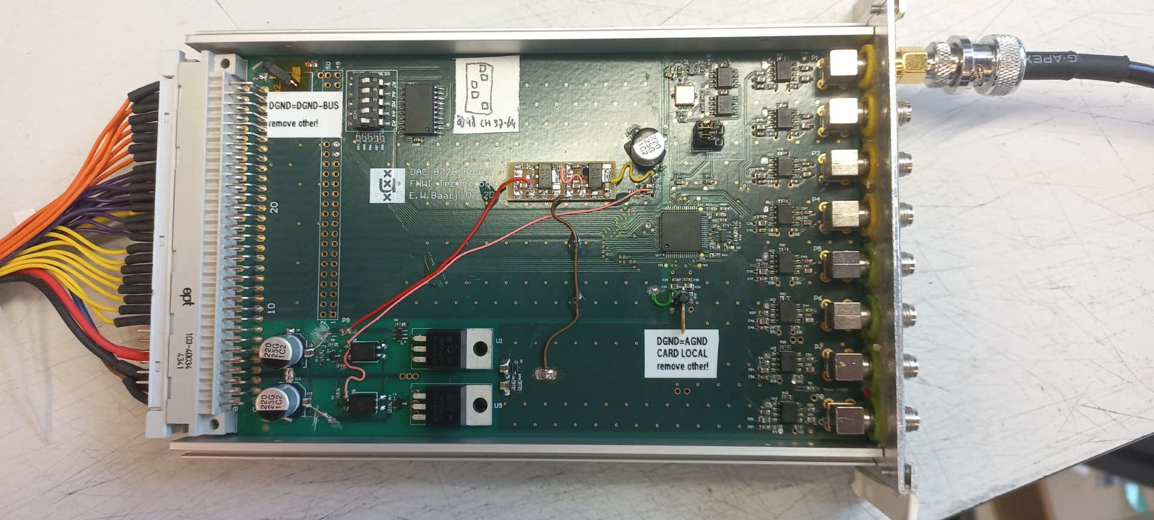
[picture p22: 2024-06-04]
Pictures/SN00 proto modified/20221007_152037 (Large).jpg

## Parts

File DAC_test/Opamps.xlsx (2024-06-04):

Item | OPA227U | OPA210IDT | OPA196 | AD8597 | OP27G | AD8675 | ADA4522 | OPA207 | OPA209 | OP113E | THP210
Noise density @100hz nV/RootHz | 3 | 2.2nV/RootHz | 18nV/Rhz | 1.5 10Hz | 3 | 2.8 | 5.8 | 9 | 2.3 | 4.7 | 3.7nV/Rhz
Noise input voltage 0.1-10Hz nVpp | 90 | 90nVpp | 1.4uVpp | 76 | 80 | 0.1 | 117 |  | 130 | 120
BandWidth (GBW) Mhz | 8 | 18Mhz | 2.5Mhz | 10 | 8Mhz | 10 | 2.7 | 1.3Mhz | 18 | 3.4 | 9.2Mhz
SlewRate V/us | 2.3 | 6.4V/us | 5.5V/us | 14 | 2.8 | 2.5 | 1.4 | 2.7 | 6.4 | 1.2 | 15V/us
Settling (0-10v, 0.01%) us | 5 | 2.6us | 2.x us | 2 | 5us ?? | 7 | 10? | 5.4us | 2.5 | 9us | 1.2us
PSRR dB | 110 | 146dB | 130 | 140 | 113 | 140 | 160 | 126 | 146 | 120 | 152
CMRR dB | 138 | 132dB | 140 | 135 | 120 | 130 | 155 | 140 | 120 | 99 Min. | 140
Input Bias nA | 10 | 0.3nA | 5pA | 40 | 10 | 0.5 | 50pA/150pA | 0.2 | 1 | 240/600 | 2nA
input offset voltage typ/max uV | 5/75 | 5/35uV | 25uV/100uV | 15/120 | 30/100 | 10/75 | 0.7/5 | 15/100 | 35/100 | -- / 75uV | 10/40uV
Vsupply-Max | ±18V | ±18 | ±20 | ±18 | ±22V | ±18 | ±27.5 | ±18V | ±20 | ±18V | ±20
Output ShortCircuit | ±45mA | ±65mA | ±65mA | 52 | ?? | ±35 | 22 | ±40mA | ±65 | ±40mA | ±31mA
Output current 20V swing | ±35mA | ±40 | ±50mA | 60 | ±17mA ??? | ±15mA ?? | 14 | ±35mA | 45 | 25mA?? | ±30mA
Iq | ±3.7mA | 2.5mA | 140uA | 4.8 | ±3mA | 2.3 | 0.8 | 250uA | 2,2mA | max 3mA | 1.0 mA
Unity Gain stable | Yes | yes | yes | yes | yes | ??? | yes | yes | yes | yes | yes
Cload Max | 4n7 (by testing) | ???? | 1nF | 1nF?? | 1.3nF ?? | ??? | 250pf | 200pf | ?? | 500pf?? | 50pf
Drift | ? | 0.1uV/C | 0.5uV/C | 0.8 | 0.2uV/C | 0.6uV/C | 22nV/C | 1uV/C | 1uV/C | 1.5uV/C | 0.35uV/C
Prijs | not available | 3.31/25+ | 2.22/25+ | 5.33/25+ | 3.4/25+ |  | 2.94/1+ digikey | 2.31/25+ | 3.53/1+ digkey | 11.06/1+ digikey | 3.24/25+
 |  | Ordered @ mouser | Ordered @ farnell | Bit high Iq | TC stock black boxes | Unclear unity gain stable | High settling, low output | OPA210=better | OPA210=better | too expensive/not good | Cload too low
Measurements CH1 |  |  |  | bit more expensive | Qty ~ 8 (check) | C_load | Marginal Cload
Slewrate 20V pos/neg edge with 10pf (scope probe) | 7.6us / 8.2us | 5.4us/5.4us
Slewrate 20V pos/neg edge with only Cload=4n7 | 7.6us / 8.2us | 5.4us/5.4us
Noise 0V DMM7510 - detector 30Hz/300Hz - No load | 117uV/65uV | 120uV/68uV
Noise 0V DMM7510 - detector 30Hz/300Hz - only Cload=4n7 | ? | 130uV/85uV
Noise -10V DMM7510 - detector 30Hz/300Hz - No load | 117uV/65uV | 118uV/65uV
Noise +10V DMM7510 - detector 30Hz/300Hz - No load | 119uV/62uV | 120uV/69uV
Delta V @Vout=+10v/10mA - noise with load 30Hz/300Hz | 52uV - 103uV/42uV | 75uV - 117uV/68uV
Delta V @Vout=-10v/10mA - noise with load 30Hz/300Hz | 50uV - 100uV/42uV | 93uV -115uV/66uV
Delta V @Vout=+10v/20mA - noise with load 30Hz/300Hz | 106uV - 112uV/62uV | 152uV - 118uV/67uV
Delta V @Vout=-10v/20mA - noise with load 30Hz/300Hz | 98uV - 100uV/45uV | 184uV - 114uV/66uV
Delta V @Vout=+10v/30mA | 158uV - 105uV/55uV | 222uV - 118uV/67uV
Delta V @Vout=-10v/30mA | 151uV - 110uV/52uV | 265uV - 116uV/66uV
Delta V @Vout=+10v/40mA | 219uV - 106uV / 42uV | 283uV - 112uV/68uV
Delta V @Vout=-10v/40mA | 209uV - 108uV/47uV | 342uV - 113uV/66uV
0v Cload mV oscillating | >4n7 | >4n7

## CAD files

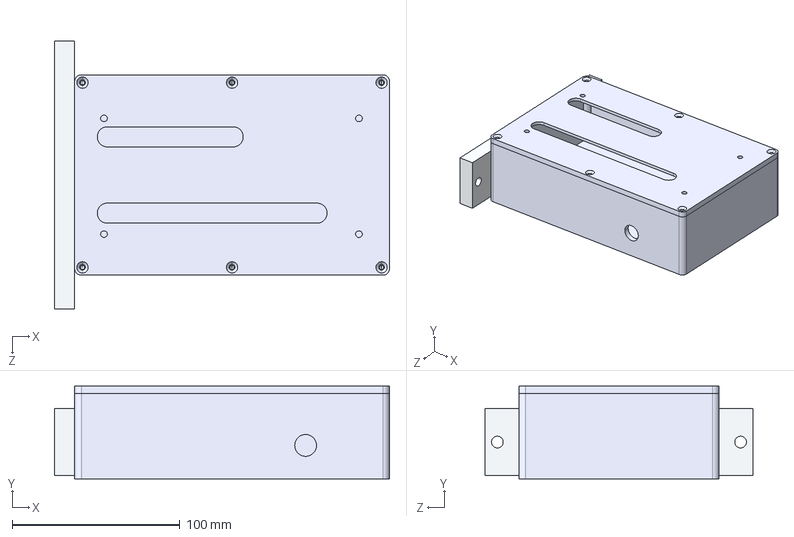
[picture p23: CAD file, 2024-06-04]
Lab Bus requirements/SubBusDriver/Box/Drawings/SubBusDriver Assembly.STEP
199.7 x 55.4 x 160.0 mm
Base188x120x57
Lid188x120x57
BusDriverBoxClamp

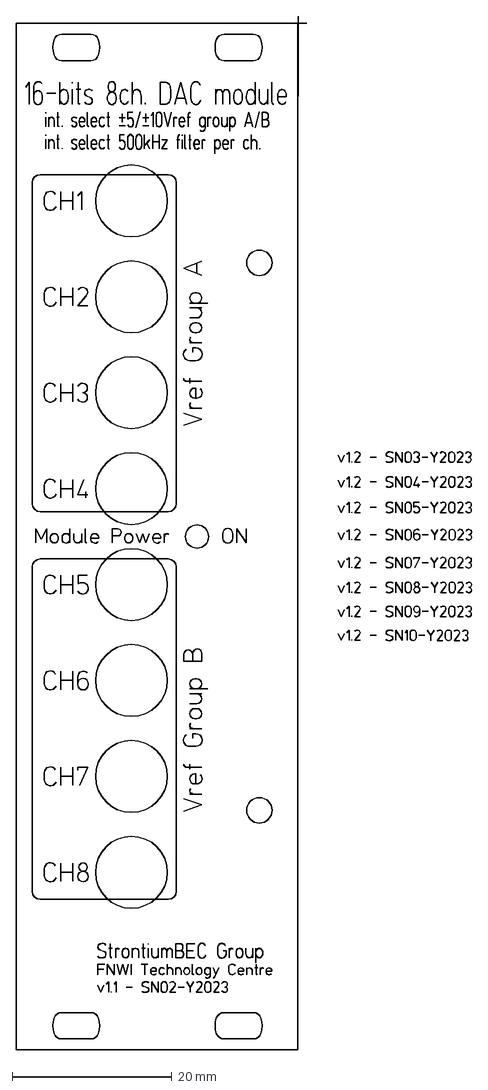
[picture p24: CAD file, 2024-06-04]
3D CAD/FrontPanelDesigner/FPD Frontplate DAC8728_Board_v11.dxf
56.9 x 129.3 mm

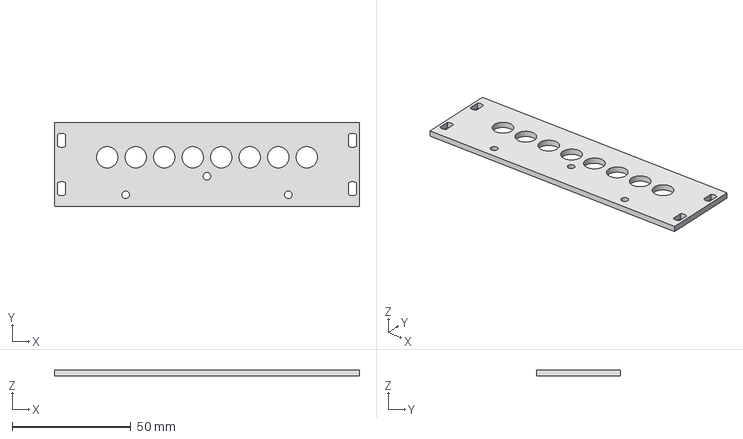
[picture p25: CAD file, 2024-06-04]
3D CAD/SendTailorSteel/Frontplate_Dac8728_v11_7HP_060423.stp
128.4 x 35.2 x 2.50 mm

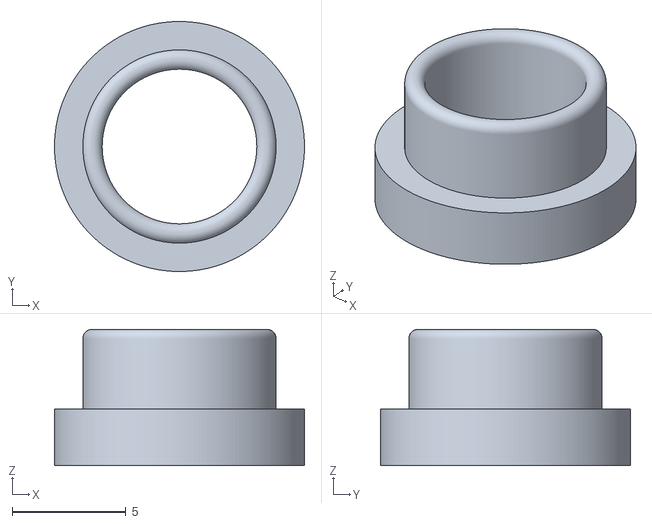
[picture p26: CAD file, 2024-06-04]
3D CAD/SubParts/SmaRing_2.5mm_3.5mm_6.8mm.stl
11.0 x 11.0 x 6.00

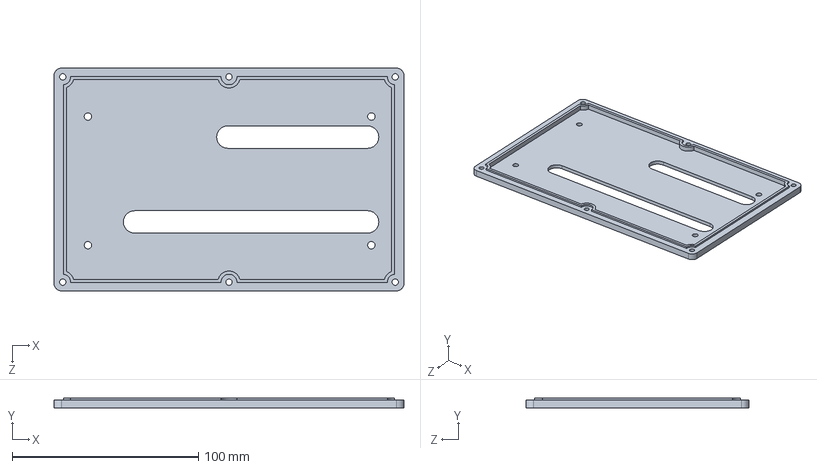
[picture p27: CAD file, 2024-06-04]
Lab Bus requirements/SubBusDriver/Box/Lid188x120x57.SLDPRT
187.7 x 5.60 x 119.5 mm

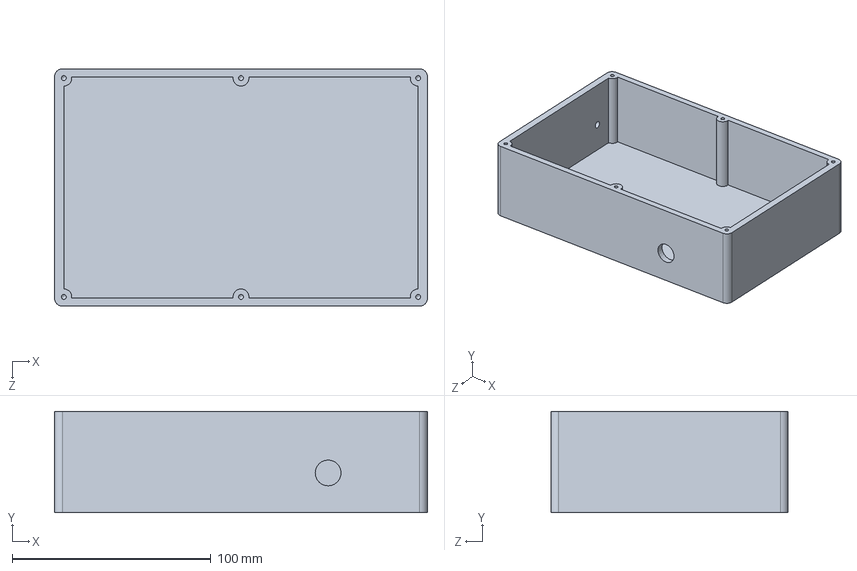
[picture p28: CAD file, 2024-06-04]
Lab Bus requirements/SubBusDriver/Box/Base188x120x57.SLDPRT
187.7 x 51.0 x 119.5 mm

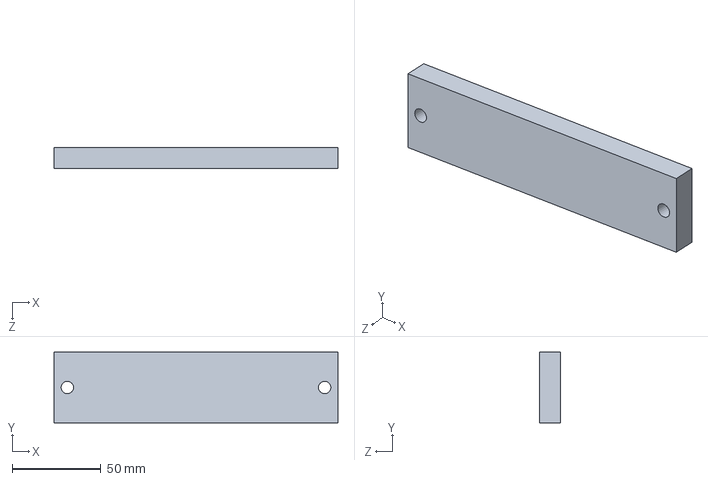
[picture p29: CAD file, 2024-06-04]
Lab Bus requirements/SubBusDriver/Box/BusDriverBoxClamp.SLDPRT
160.0 x 40.0 x 12.0 mm

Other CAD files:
Lab Bus requirements/SubBusDriver/Box/SubBusDriver Assembly.SLDASM
3D CAD/Templates/English/ANSI (in).dwg
3D CAD/Templates/Metric/DIN.dwg
3D CAD/Templates/standard.dwg
Lab Bus requirements/SubBusDriver/Driver4BusV1.1/Driver4Bus V1.DWG
3D CAD/Templates/Metric/GOST.dwg
3D CAD/Templates/Metric/JIS.dwg
3D CAD/Templates/Metric/BSI.dwg
3D CAD/Templates/Metric/ANSI (mm).dwg
3D CAD/Templates/Metric/GB.dwg
3D CAD/Templates/Metric/ISO.dwg
3D CAD/FME7_Cap.ipt
3D CAD/Frontplate_Dac8728_v12_decal.ipt
3D CAD/GP193-166.ipt
3D CAD/SmaRing_2.5mm_3.5mm_6.8mm.ipt
3D CAD/SubParts/OldVersions/BNC_RG174_AdaptRing_10mm_3mm.0001.ipt
3D CAD/SubParts/OldVersions/Fischer FME 7 Hood Profile Slice25mm.0002.ipt
3D CAD/SubParts/OldVersions/SMB_Half_Shell.0002.ipt
3D CAD/SubParts/OldVersions/SmaRing_1.5mm_3.5mm.0002.ipt
3D CAD/SubParts/OldVersions/SmaRing_2.5mm_3.0mm_6.8mm.0001.ipt
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

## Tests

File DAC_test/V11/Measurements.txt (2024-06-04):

//=====OptoCouplers

U5(PS250...) V_R4=3.8V@1K8=2.1mA Uce=0.16V  U6 is ~equal
U20(VOM618..) V_R12=16.9V@4K7=3.6mA Uce=0.17V

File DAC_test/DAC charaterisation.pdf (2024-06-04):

# Performance of Old Vs New Analog output boxes Wednesday, August 24, 2022 8:09 PM

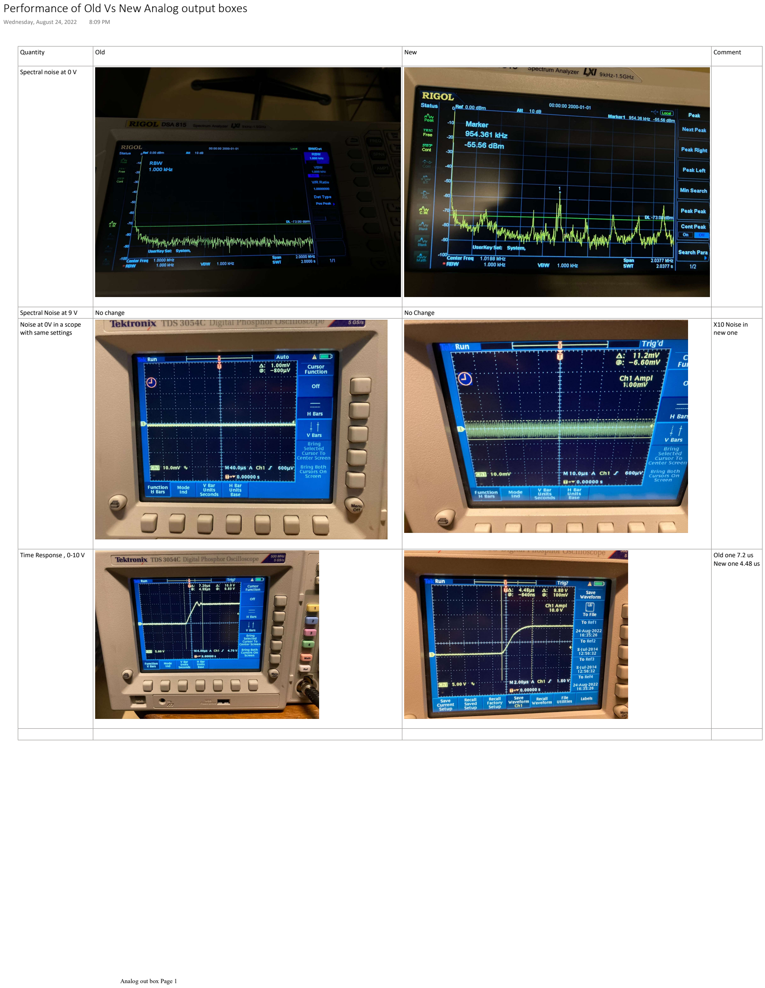
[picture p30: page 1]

Quantity | Old | New | Comment Spectral noise at 0 V
Spectral Noise at 9 V | No change | No Change Noise at 0V in a scope with same settings | X10 Noise in new one
Time Response , 0-10 V | | | Old one 7.2 us New one 4.48 us

Analog out box Page 1

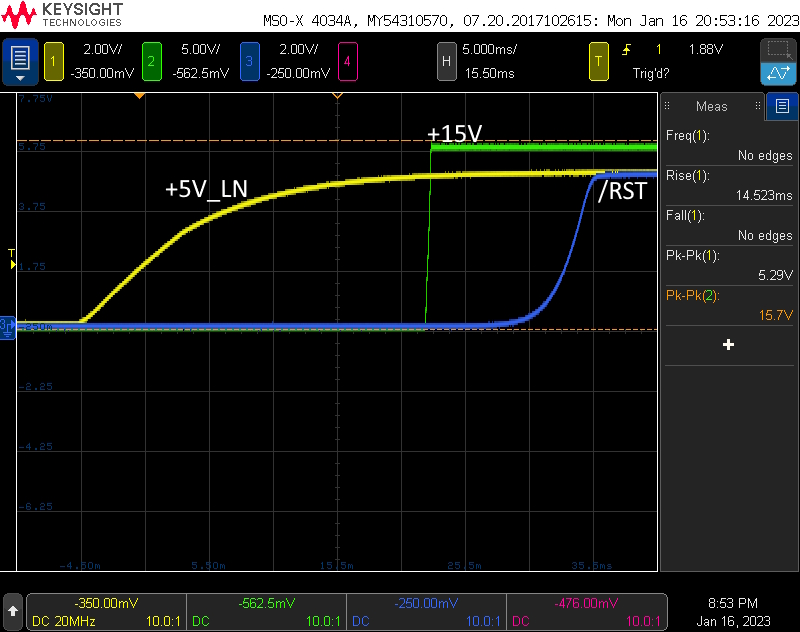
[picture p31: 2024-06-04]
DAC_test/V11/RC_times_5_12_RST.jpg

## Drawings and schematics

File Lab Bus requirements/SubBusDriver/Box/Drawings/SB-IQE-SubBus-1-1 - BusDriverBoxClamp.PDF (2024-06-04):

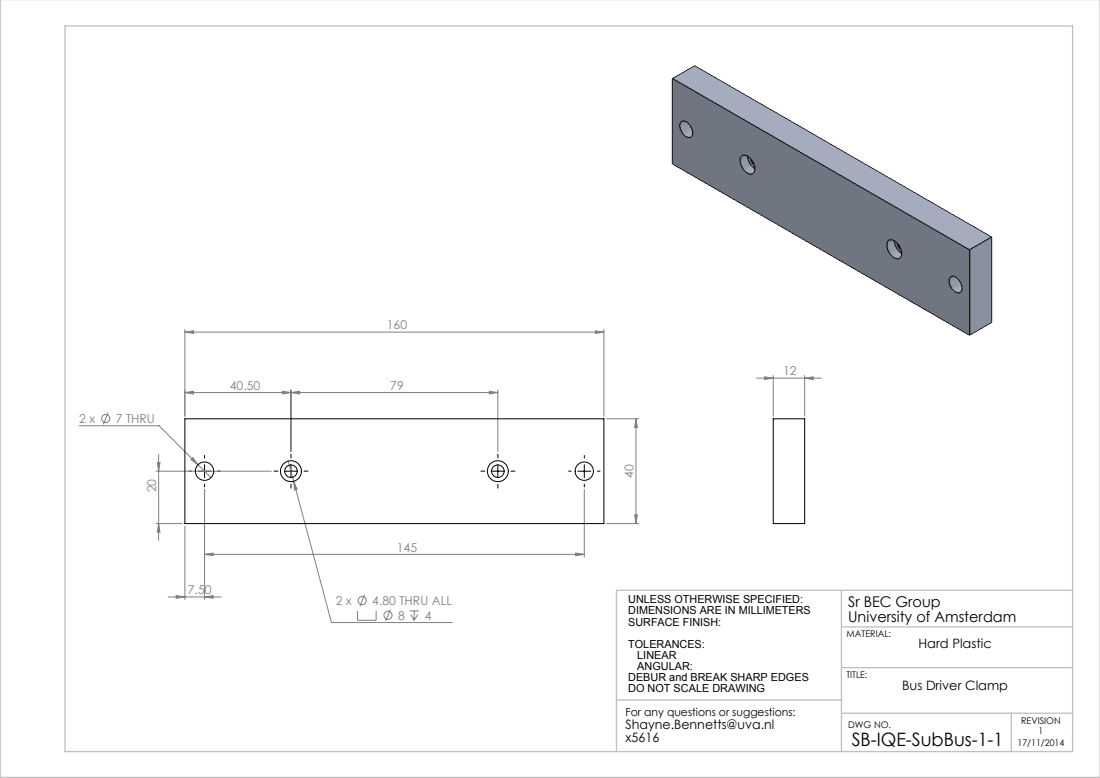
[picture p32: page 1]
7 THRU; 4.80 THRU ALL; DWG NO.; Hard Plastic

UNLESS OTHERWISE SPECIFIED:
DIMENSIONS ARE IN MILLIMETERS
SURFACE FINISH:
TOLERANCES:
LINEAR
ANGULAR:
DEBUR and BREAK SHARP EDGES
DO NOT SCALE DRAWING
REVISION For any questions or suggestions:
Shayne.Bennetts@uva.nl

Sr BEC Group
University of Amsterdam
MATERIAL:

Bus Driver Clamp

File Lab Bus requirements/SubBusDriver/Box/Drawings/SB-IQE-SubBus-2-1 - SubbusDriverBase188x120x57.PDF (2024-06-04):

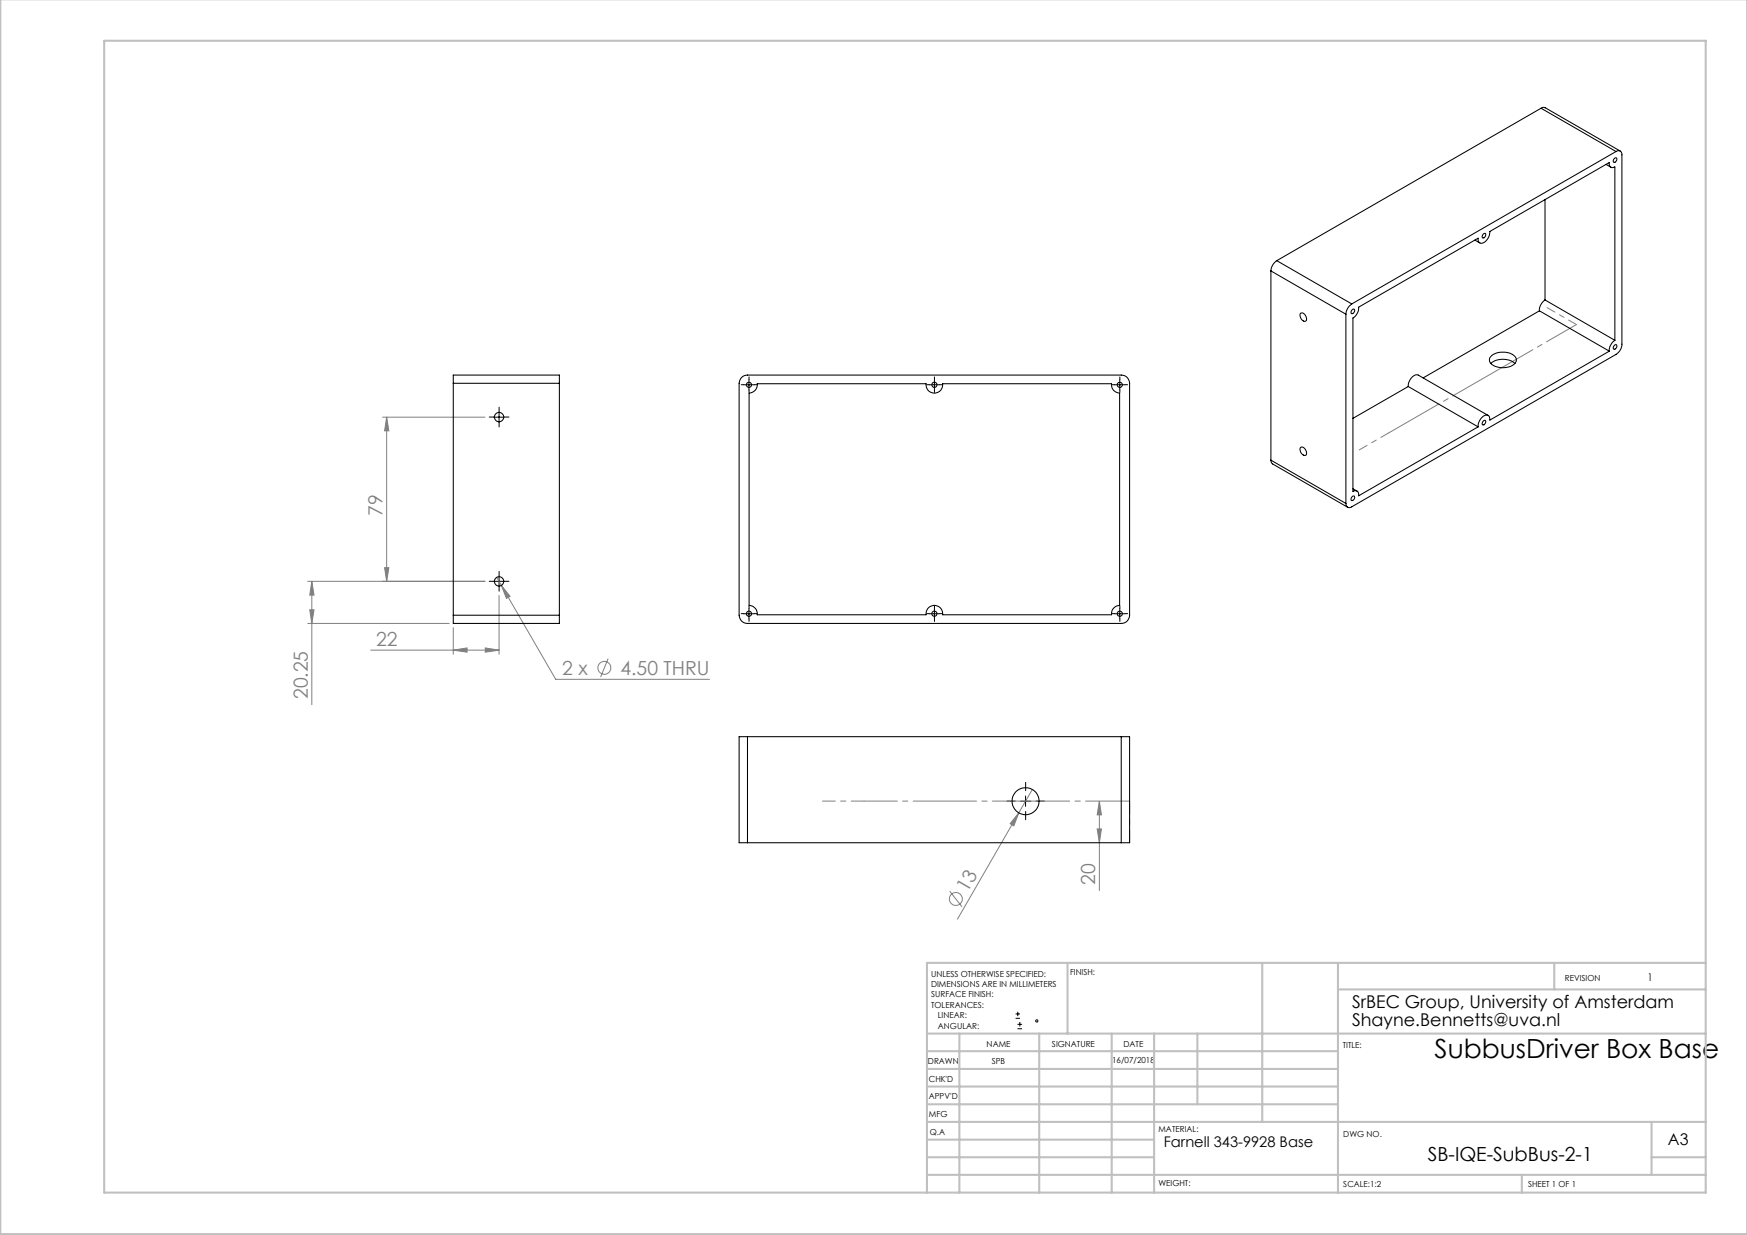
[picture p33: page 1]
4.50 THRU; SCALE:1:2; SHEET 1 OF 1; UNLESS OTHERWISE SPECIFIED:; FINISH:; DRAWN; SubbusDriver Box Base

DIMENSIONS ARE IN MILLIMETERS
SURFACE FINISH:
TOLERANCES:
LINEAR:
ANGULAR:

SrBEC Group, University of Amsterdam
Shayne.Bennetts@uva.nl

NAME | SIGNATURE | DATE | | | | TITLE:
SPB | | 16/07/2018

CHK'D
APPV'D
MFG
Q.A | | | | MATERIAL: Farnell 343-9928 Base | DWG NO. SB-IQE-SubBus-2-1 | A3

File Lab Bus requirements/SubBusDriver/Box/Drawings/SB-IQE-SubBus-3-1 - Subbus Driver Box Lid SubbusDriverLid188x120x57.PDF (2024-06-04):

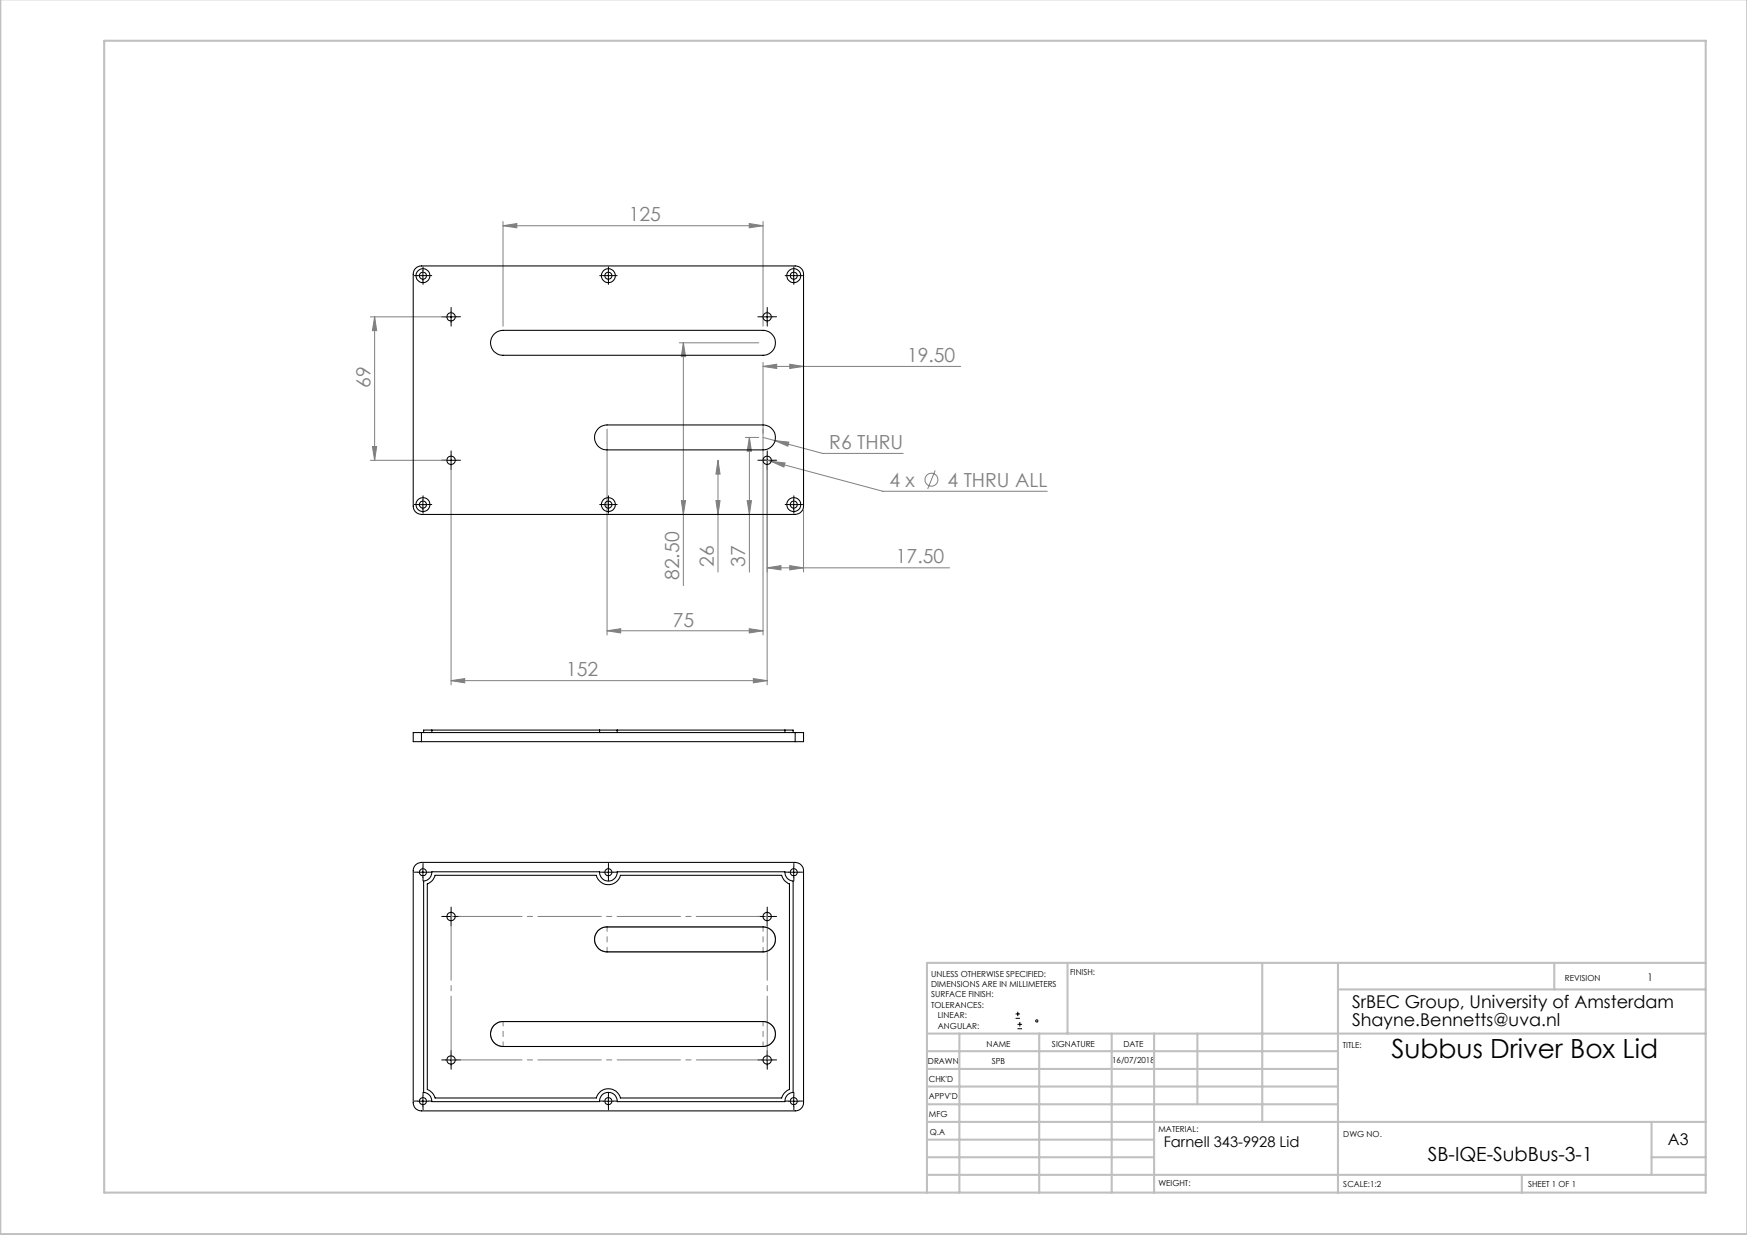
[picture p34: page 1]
4 THRU ALL; R6 THRU; SCALE:1:2; SHEET 1 OF 1; UNLESS OTHERWISE SPECIFIED:; FINISH:

DIMENSIONS ARE IN MILLIMETERS
SURFACE FINISH:
TOLERANCES:
LINEAR:
ANGULAR:

SrBEC Group, University of Amsterdam
Shayne.Bennetts@uva.nl

DRAWN | NAME | SIGNATURE | DATE | | | | Subbus Driver Box Lid TITLE:

SPB | | 16/07/2018

CHK'D
APPV'D
MFG
Q.A | | | | MATERIAL: Farnell 343-9928 Lid | DWG NO. SB-IQE-SubBus-3-1 | A3

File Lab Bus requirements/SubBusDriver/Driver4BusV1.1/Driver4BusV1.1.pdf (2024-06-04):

D | S

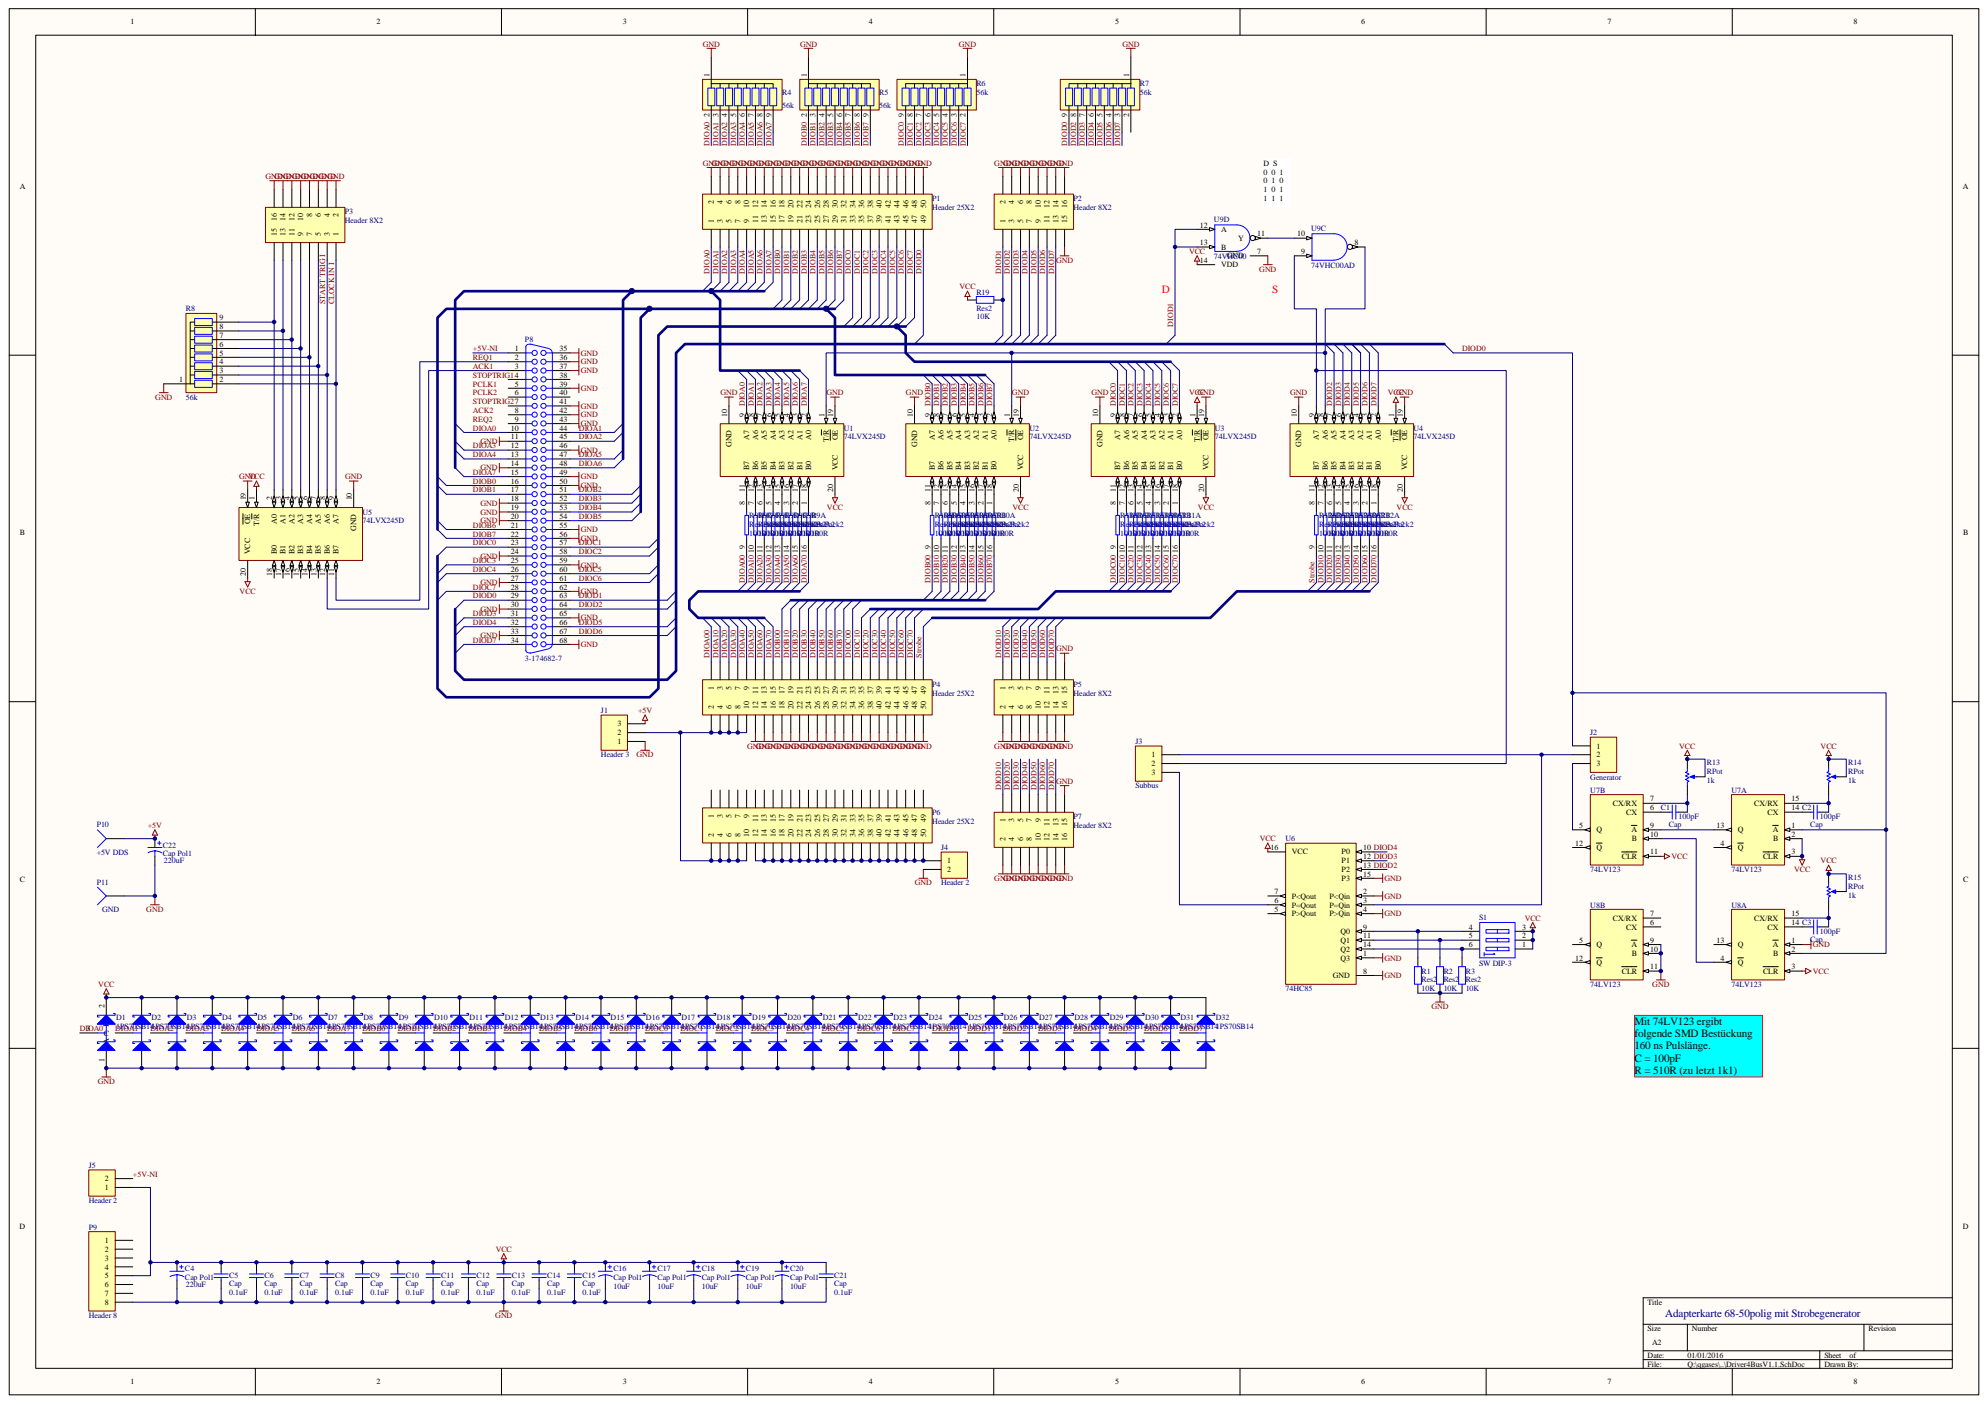
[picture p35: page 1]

1 16 100R R9A Res Pack2 1 16 100R R10A Res Pack2 8 9 100R R11H Res Pack2 4 13 100R R12D Res Pack2 5 12 100R R12E Res Pack2 7 10 100R R11G Res Pack2 2 15 100R R10B Res Pack2 2 15 100R R9B Res Pack2 3 14 100R R9C Res Pack2 3 14 100R R10C Res Pack2 6 11 100R R11F Res Pack2 6 11 100R R12F Res Pack2 4 13 100R R9D Res Pack2 4 13 100R R10D Res Pack2 5 12 100R R11E Res Pack2 1 16 100R R12A Res Pack2 5 12 100R R10E Res Pack2 4 13 100R R11D Res Pack2 7 10 100R R12G Res Pack2 5 12 100R R9E Res Pack2 6 11 100R R9F Res Pack2 6 11 100R R10F Res Pack2 3 14 100R R11C Res Pack2 2 15 100R R12B Res Pack2 7 10 100R R9G Res Pack2 7 10 100R R10G Res Pack2 2 15 100R R11B Res Pack2 8 9 100R R12H Res Pack2 8 9 100R R9H Res Pack2 8 9 100R R10H Res Pack2 1 16 100R R11A Res Pack2 3 14 100R R12C Res Pack2 VCC VCC VCC VCC

Size A2 | Number | Revision

Date: 01/01/2016 | Sheet of
File: Q:\qgases\..\Driver4BusV1.1.SchDoc | Drawn By:

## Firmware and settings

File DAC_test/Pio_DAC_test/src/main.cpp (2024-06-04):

#include <Arduino.h>
#include <SimpleCLI.h>

void(* resetFunc) (void) = 0;

SimpleCLI cli;

  

#define RdWr 39
#define strobePin 41

#define ChCnt 8

char buffer[50];
uint16_t LastVout[8];                                         //last set output for channel 
uint8_t LastCh;                                               //last channel set
uint16_t SquareVoutPos;                                       //used in command ss and sa
uint16_t SquareVoutNeg;
boolean DoSquareSync=false;
boolean DoSquareAlt=false;
boolean DoSquareChan=false;
boolean DoDataBusNoise=false;
boolean SquareTgl;

uint16_t VoltToUSB(float Vout) {
  if (Vout>9.9997) Vout=9.9997;
  return((uint16_t)( ((Vout + 10) / 20) * 65536 ));
}

void SetVout(uint8_t Ch, boolean Show=0) {
  char fbuf[10];
  PORTA = Ch+48;                                                 //Base (A7-A3) set to b.0011.0dddsa 
  PORTC = highByte(LastVout[Ch]);
  PORTL = lowByte(LastVout[Ch]);
  //digitalWrite(RdWr, LOW);                 //>>debug
  digitalWrite(strobePin, HIGH);
  digitalWrite(strobePin, LOW);
  //digitalWrite(RdWr, HIGH);                //>>Debugv 8
  if (Show) {
    double Vout = ((double)LastVout[Ch] * 20/65536)-10;
    dtostrf(Vout,6,4,fbuf);
    sprintf(buffer," Set Ch%u to %sV (bin. 0x%x)", Ch+1, fbuf, LastVout[Ch]); 
    Serial.println(buffer);
  }  
}

void CB_FwRst(cmd * c) {
  Command cmd(c);                                             // Create wrapper object  
  Serial.print("Soft Resetting now.."); 
  delay(100);
  resetFunc();
}

void CB_SetAllChan(cmd *c) {                                  //sa <Vout>
  Command cmd(c);
  int argNum = cmd.countArgs();                               // Get number of arguments
  if (argNum>1) {Serial.println("Parm error!"); return;}
  Argument arg = cmd.getArg(0);
  String sVout= arg.getValue();
  float Vout = sVout.toFloat();
  for (uint8_t i=0; i<ChCnt; i++) {
    LastVout[i]= VoltToUSB(Vout);
    SetVout(i,true); 
  }
}

void CB_SquareChan(cmd *c) {                                  //Q <channel> <vout>
  Command cmd(c);
  int argNum = cmd.countArgs();                               // Get number of arguments
  if (argNum<2) {Serial.println("Parm error!"); return;}
  Argument arg = cmd.getArg(0);
  String sCh= arg.getValue();
  uint8_t ch= sCh.toInt();
  LastCh = ch-1; 
  arg = cmd.getArg(1);
  String sVout= arg.getValue();
  float Vout = sVout.toFloat();
  if (Vout>=0) {
    SquareVoutPos = VoltToUSB(Vout);   
    Vout *= -1;
    SquareVoutNeg = VoltToUSB(Vout);   
  } else {
    SquareVoutNeg = VoltToUSB(Vout);   
    Vout *= -1;
    SquareVoutPos = VoltToUSB(Vout);   
  } 
  DoSquareChan=true;
  sprintf(buffer," Single Channel SquareWaveSync: 0x%x <-> 0x%x)", SquareVoutNeg, SquareVoutPos ); 
  Serial.println(buffer);
}

void CB_SquareSync(cmd* c) {                                  //Qs <Vout>
  Command cmd(c);
  int argNum = cmd.countArgs();                               // Get number of arguments
  if (argNum>1) {Serial.println("Parm error!"); return;}
  Argument arg = cmd.getArg(0);
  String sVout= arg.getValue();
  float Vout = sVout.toFloat();
  if (Vout>=0) {
    SquareVoutPos = VoltToUSB(Vout);   
    Vout *= -1;
    SquareVoutNeg = VoltToUSB(Vout);   
  } else {
    SquareVoutNeg = VoltToUSB(Vout);   
    Vout *= -1;
    SquareVoutPos = VoltToUSB(Vout);   
  }
  DoSquareSync=true;
  sprintf(buffer," All channel SquareWaveSync: 0x%x <-> 0x%x)", SquareVoutNeg, SquareVoutPos ); 
  Serial.println(buffer);
}


void CB_SquareAlt(cmd* c) {                                   //qa <Vout>
  Command cmd(c);
  int argNum = cmd.countArgs();                               // Get number of arguments
  if (argNum>1) {Serial.println("Parm error!"); return;}
  Argument arg = cmd.getArg(0);
  String sVout= arg.getValue();
  float Vout = sVout.toFloat();
  if (Vout>=0) {
    SquareVoutPos = VoltToUSB(Vout);   
    Vout *= -1;
    SquareVoutNeg = VoltToUSB(Vout);   
  } else {
    SquareVoutNeg = VoltToUSB(Vout);   
    Vout *= -1;
    SquareVoutPos = VoltToUSB(Vout);   
  }
  DoSquareAlt=true;
  sprintf(buffer," All channel SquareWaveAlt: 0x%x <-> 0x%x)", SquareVoutNeg, SquareVoutPos ); 
  Serial.println(buffer);

}

void CB_NoiseDataBus(cmd* c) {                                //nd <option>
  Command cmd(c);
  int argNum = cmd.countArgs();                               // Get number of arguments
  if (argNum>1) {Serial.println("Parm error!"); return;}
  Argument arg = cmd.getArg(0);

  String sOption= arg.getValue();
  uint8_t Option = sOption.toInt();

  switch(Option) {
    case 0:
      PORTC = 0;  PORTL = 0;
      sprintf(buffer," Databus set to 0x0000"); 
      return;
    case 1:
      PORTC = 0xff; PORTL = 0xff;
      sprintf(buffer," Databus set to 0xFFFF"); 
      return;
    case 3:
      SquareVoutPos=0xFFFF;
      SquareVoutNeg=0x0;
      break;
    default:
      SquareVoutPos=0xAAAA;
      SquareVoutNeg=0x5555;
      break;
  }   
  DoDataBusNoise=true;
  sprintf(buffer," Noise on the databus: 0x%x <-> 0x%x)", SquareVoutNeg, SquareVoutPos ); 
  Serial.println(buffer);
}


void CB_ChanVout(cmd* c) {                                    // v <ch> <float value>: Set Vout for ch 
  Command cmd(c);                                             // Create wrapper object
  int argNum = cmd.countArgs();                               // Get number of arguments
  if (argNum<2) {Serial.println("Parm error!"); return;}
  Argument arg = cmd.getArg(0);
  String sCh= arg.getValue();
  uint8_t ch= sCh.toInt();
  arg = cmd.getArg(1);
  String sVout= arg.getValue();
  float Vout = sVout.toFloat();
  if (Vout>9.9997) Vout=9.9997;
  uint16_t BinVal = VoltToUSB(Vout);   
  LastCh = ch-1;                                              //For user channel numbers ar 1...4 !!
  LastVout[LastCh]=BinVal; 
  SetVout(LastCh, true);
}

void CB_ChanBinVout(cmd* c) {                                 // b <ch> <Hex Value>: Set Vout for ch 
  char *s;
  long BinVal;
  char buf[4];
  Command cmd(c);                                             // Create wrapper object
  int argNum = cmd.countArgs();                               // Get number of arguments
  if (argNum<2) {Serial.println("Parm error!"); return;}
  Argument arg = cmd.getArg(0);
  String sCh= arg.getValue();
  uint8_t ch= sCh.toInt();
  arg = cmd.getArg(1);
  String sVout= arg.getValue();
  sVout.toCharArray(buf,5);                                   //WHY 5??? 4 will read 0xFFF 
  BinVal = strtol(buf,&s,0x10); 
  LastCh = ch-1;                                              //For user channel numbers ar 1...4 !!
  LastVout[LastCh]=(uint16_t)BinVal; 
  SetVout(LastCh, true);
}

// Callback in case of an error
void errorCallback(cmd_error* e) {
    CommandError cmdError(e); // Create wrapper object

    Serial.print("ERROR: ");
    Serial.println(cmdError.toString());

    if (cmdError.hasCommand()) {
        Serial.print("Did you mean \"");
        Serial.print(cmdError.getCommand().toString());
        Serial.println("\"?");
    }
}


Command ChanVout;                             //v <ch> <Value>  (decimal)
Command ChanBinVout;                          //b <ch> <hexValue.
Command FwReset;                              //rst
Command SquareChan;                           //qc <ch> <Vout>  
Command SquareSync;                           //qs <Vout>
Command SquareAlt;                            //qa <Vout>
Command SetAllChan;                           //sa <vout>
Command NoiseDataBus;                         //nd <noise choice>

void setup() {
    DDRA = 0Xff;
    DDRC = 0Xff;
    DDRL = 0Xff;
    PORTA = 0; // set PORTA (digital 7~0) to outputs           //Card Address A7-A0
    PORTC = 0; // set PORTC (digital 7~0) to outputs           //Dac DataBus D15-D8
    PORTL = 0; // set PORTL (digital 7~0) to outputs           //Dac DataBus D7-D0
    pinMode(strobePin, OUTPUT); digitalWrite(strobePin, LOW);
    pinMode(RdWr, OUTPUT); digitalWrite(RdWr, HIGH);
    LastCh=0;
    LastVout[0]=0x8000;LastVout[1]=0x8000;LastVout[2]=0x8000;LastVout[3]=0x8000;
    LastVout[4]=0x8000;LastVout[5]=0x8000;LastVout[6]=0x8000;LastVout[7]=0x8000;

    Serial.begin(9600);                                               // Enable Serial connection at given baud rate
    Serial.setTimeout(10000);
    
    ChanVout = cli.addBoundlessCommand("v", CB_ChanVout);
    SetAllChan = cli.addBoundlessCommand("sa", CB_SetAllChan);
    ChanBinVout = cli.addBoundlessCommand("b", CB_ChanBinVout);
    FwReset = cli.addBoundlessCommand("rst", CB_FwRst);
    SquareChan= cli.addBoundlessCommand("qc", CB_SquareChan);
    SquareSync = cli.addBoundlessCommand("qs", CB_SquareSync);
    SquareAlt = cli.addBoundlessCommand("qa", CB_SquareAlt);
    NoiseDataBus = cli.addBoundlessCommand("nb", CB_NoiseDataBus);

    cli.setOnError(errorCallback);                                    // Set error Callback
    Serial.print("\n** Dac test firmware **\nCommand: ");                                 // Start the loop
    pinMode(strobePin, OUTPUT); 
}

String input;
boolean DoSetVoutUD=false;

void loop() {
  // Check if user typed something into the serial monitor
  if (Serial.available()) { 
    DoSquareSync=false;                                   //any input stops all the Squarewaving
    DoSquareAlt=false;
    DoSquareChan = false;
    DoDataBusNoise = false;
    int ib = Serial.read();
    if (ib =='\n') {
      cli.parse(input);                                   // Parse the input
      input="";
      Serial.print("Command: ");
    } else if (ib=='u') {                                 // increase the voltage value of last outputted channel by 1 lsb
      if (LastVout[LastCh]<0xFFFF) {                      // boundary increment
        LastVout[LastCh]+=1;   
        DoSetVoutUD=true;
      }  
    } else if (ib=='d') {                                 // decrease the voltage value of last outputted channel by 1 lsb                              
      if (LastVout[LastCh]>0) {                           // boundary decrement  
        LastVout[LastCh]-=1;        
        DoSetVoutUD=true;
      }  
    } else {
      input += char(ib);
    }  

    if (DoSetVoutUD) {
      Serial.println();
      SetVout(LastCh,true); 
      DoSetVoutUD=false;
      Serial.print("\nCommand: ");
    }  
  } // close if (serial.available....



  if (DoSquareChan) {
    SquareTgl=!SquareTgl;
    if (SquareTgl) LastVout[LastCh]=SquareVoutPos; else LastVout[LastCh]=SquareVoutNeg;
    SetVout(LastCh,false); 
  } else if (DoSquareSync) {
    SquareTgl=!SquareTgl;
    for (uint8_t i=0; i<ChCnt; i++) {
      if (SquareTgl) LastVout[i]=SquareVoutPos; else LastVout[i]=SquareVoutNeg;
      SetVout(i,false); 
      //delay(100); Serial.print(".");
    }
  } else if (DoSquareAlt) {
    SquareTgl=!SquareTgl;
    for (uint8_t i=0; i<ChCnt; i++) {
      if (SquareTgl) { 
        if (i==0 || i==2 || i==4 || i==6) LastVout[i]=SquareVoutPos; 
        if (i==1 || i==3 || i==5 || i==7) LastVout[i]=SquareVoutNeg; 
      } else {
        if (i==0 || i==2 || i==4 || i==6) LastVout[i]=SquareVoutNeg; 
        if (i==1 || i==3 || i==5 || i==7) LastVout[i]=SquareVoutPos;  
      } 
      SetVout(i,false); 
    }
  } else if (DoDataBusNoise) {
    SquareTgl=!SquareTgl;
    if (SquareTgl) { 
      PORTC = highByte(SquareVoutPos); 
      PORTL = lowByte(SquareVoutPos);
    } else {
      PORTC = highByte(SquareVoutNeg); 
      PORTL = lowByte(SquareVoutNeg);
    }  
  }

}

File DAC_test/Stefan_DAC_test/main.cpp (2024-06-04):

#include <Arduino.h>

// Include Library
#include <SimpleCLI.h>

// Create CLI Object
SimpleCLI cli;

// Commands
Command setOutput;
Command setChannel;
Command move;
Command rampUp;

const int strobePin = 41;
float voltVal = 0;
unsigned int binaryVal = 0;
byte address = B11111111;
bool rampUpFlag = false;

// Callback function for ping command
void outputCallback(cmd* c) {
    Command cmd(c); // Create wrapper object
    Argument argVolt = cmd.getArgument("s");    
    String argVoltVal = argVolt.getValue();
    voltVal = argVoltVal.toInt();
    binaryVal = ((voltVal + 10) / 20) * 65535;   
    
    Serial.println("Output set to " + argVoltVal + "V");
}

void channelCallback(cmd* c) {
    Command cmd(c); // Create wrapper object
    Argument argNum = cmd.getArgument("s");
    String argNumVal = argNum.getValue();
    int num = argNumVal.toInt();
    address = num - 1 + 252;
    PORTA = address;    
    
    Serial.println("Channel " + argNumVal + "  selected");
}

void moveCallback(cmd* c) {
    Command cmd(c); // Create wrapper object
    Argument argBits = cmd.getArgument("s");    
    String argBitsVal = argBits.getValue();
    unsigned int bitsVal = argBitsVal.toInt();     
    binaryVal += bitsVal;  
    
    Serial.print("Output set to ");
    Serial.print(binaryVal);
    Serial.println();
}

void rampUpCallback(cmd* c) {
    Command cmd(c); // Create wrapper object
    rampUpFlag = !rampUpFlag;
    if(rampUpFlag){
        Serial.println("Zagen..");
    } 
    else{
        Serial.println("Gestopt met zagen.");
    }
}

// Callback in case of an error
void errorCallback(cmd_error* e) {
    CommandError cmdError(e); // Create wrapper object

    Serial.print("ERROR: ");
    Serial.println(cmdError.toString());

    if (cmdError.hasCommand()) {
        Serial.print("Did you mean \"");
        Serial.print(cmdError.getCommand().toString());
        Serial.println("\"?");
    }
}


void setup() {
    // Enable Serial connection at given baud rate
    Serial.begin(9600);

    // Wait a bit until device is started
    delay(2000);
    
    setOutput = cli.addCmd("v", outputCallback);
    setChannel = cli.addCmd("ch", channelCallback);
    move = cli.addCmd("m", moveCallback);
    rampUp = cli.addCmd("ramp", rampUpCallback);

    // [Optional] Check if our command was successfully added
    if (!setOutput || !setChannel) {
        Serial.println("Something went wrong :(");
    } else {
        Serial.println("CLI started");
    }

    // Set error Callback
    cli.setOnError(errorCallback);

    // Start the loop
    Serial.println("Type a command");

    setOutput.addArgument("s");
    setChannel.addArgument("s");
    move.addArgument("s");

    
    DDRA = B11111111; // set PORTA (digital 7~0) to outputs
    DDRC = B11111111; // set PORTA (digital 7~0) to outputs
    DDRL = B11111111; // set PORTA (digital 7~0) to outputs
    
    pinMode(strobePin, OUTPUT); 
}

void loop() {
    // Check if user typed something into the serial monitor
    if (Serial.available()) {
        // Read out string from the serial monitor
        String input = Serial.readStringUntil('\n');

        // Echo the user input
        Serial.print("# ");
        Serial.println(input);

        // Parse the user input into the CLI
        cli.parse(input);
    }

    if(rampUpFlag){
      binaryVal += 1;
      if(binaryVal == 65535){
        binaryVal = 0;
      }
    }
    
    PORTC = highByte(binaryVal);
    PORTL = lowByte(binaryVal);
    digitalWrite(strobePin, HIGH);
    digitalWrite(strobePin, LOW);
}
